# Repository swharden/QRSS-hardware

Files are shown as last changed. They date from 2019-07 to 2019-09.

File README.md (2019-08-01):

# QRSS Hardware

This repository is an evolving collection of notes and resources related to QRSS hardware (TX and RX) that I (Scott Harden, AJ4VD) find useful. Eventually this work will become a webpage, but for now it's a GitHub repository which makes it easy to edit.

* **[Recently spotted AJ4VD QRSS signals](/spots)**
* Hardware notes are in the [builds](/builds) folder 
* New to QRSS?
  * [What is QRSS?](https://www.qsl.net/m0ayf/What-is-QRSS.html)
  * Join the [_QRSS Knights_ mailing list](https://groups.io/g/qrssknights)
  * See live signals around the world with [QRSS Plus](http://www.swharden.com/qrss/plus/)

### Modular QRSS Transmitter for Experimentation

The transmitter I built uses separate modules. I designed my transmitter this way so I can get a signal on the air, then work toward improving individual modules individually. My current design supports FSK (frequency-shift keying), OOK (on-off keying), and adjustable power output, and synchronization with GPS time. 

Modules are all individually powered and use SMA connectors for inputs/outputs. By applying this [SOLID](https://www.youtube.com/watch?v=TMuno5RZNeE&t=15m50s) principle to hardware development, the system easy to refactor (because it reduces _coupling_) and individual units are easy to test (because they have a defined _interface_).

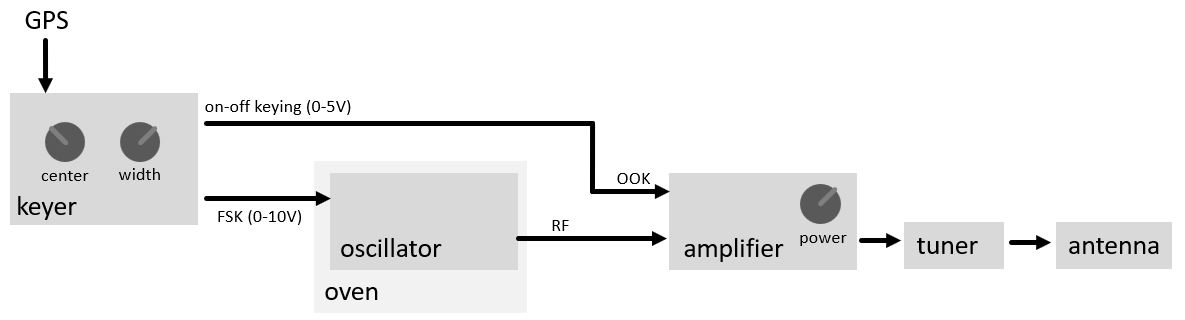
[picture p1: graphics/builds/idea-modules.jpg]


* **oscillator** - Colpitts, 10.140 MHz crystal, no inductors (so SMT PCB is easy), outputs about 1 mW
* **oscillator oven** - uses two power 50 Ohm resistors to heat the _entire oscillator enclosure_ to above ambient room temperature. Thermistor is used for temperature sensation. By heating an entire metal-enclosed oscillator module, the entire oscillator circuitry (not just the crystal) becomes thermo-stable.
* **keyer** - based on an ATTiny2313 microcontroller. Keying is pulse-width modulated (PWM), and OOK output is also provided. Keyer has voltage combiner which has separate knobs to adjust center frequency and FSK width. Output is a single voltage for the oscillator, and a signal voltage for the amplifier. While it's currently configured for OOK, an analog voltage could be sent to the amplifier to control power output from software.
* **GPS** - To start messages at precise 10 minute intervals a GPS module (Neo-6M) is used. Rather than tap into the 1PPS signal line, I'm using the microcontroller to parse the serial data coming off the chip and begin transmitting at precise times.
* **amplifier** - currently an IRF510 final transistor with  74HC541 buffer pre-amplifier. The 74HC541's enable lines are controlled by the keyer to provide OOK. A potentiometer sets the power output. The current design has been tested to over 10W but this is an unnecessary (and undesirable) power level for QRSS.
* **frequency counter** - this is an independent project at the moment. I'm creating a USB frequency counter which will be useful for graphing frequency stability over time (and its relationship with temperature). I'll link to this once I have it tested/working.
* **antenna** - 30m dipole in my attic (Gainesville, Florida, USA)

### Photographs

This is a work in progress so the enclosures (if they even exist) are pretty crude. Additional photographs (and schematics) at various stages of the design process can be found in sub-folders of this repository. As individual modules are improved, these photographs will be updated.

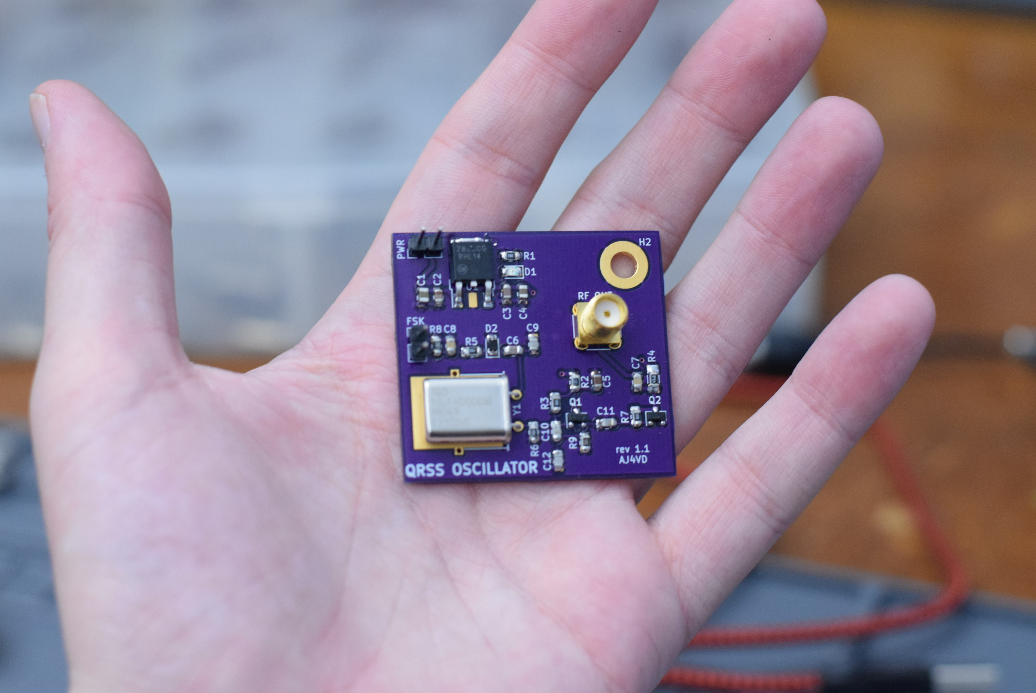
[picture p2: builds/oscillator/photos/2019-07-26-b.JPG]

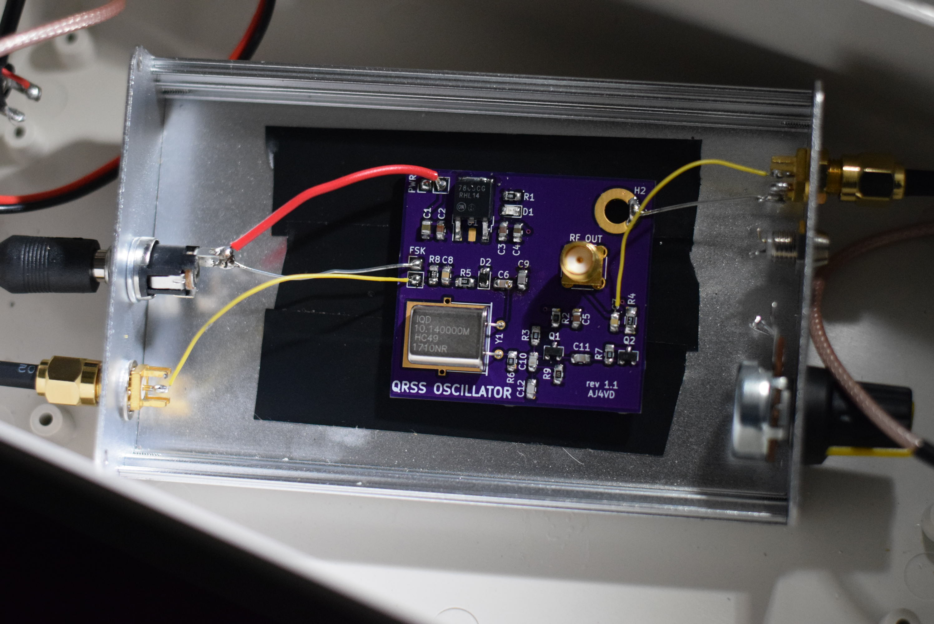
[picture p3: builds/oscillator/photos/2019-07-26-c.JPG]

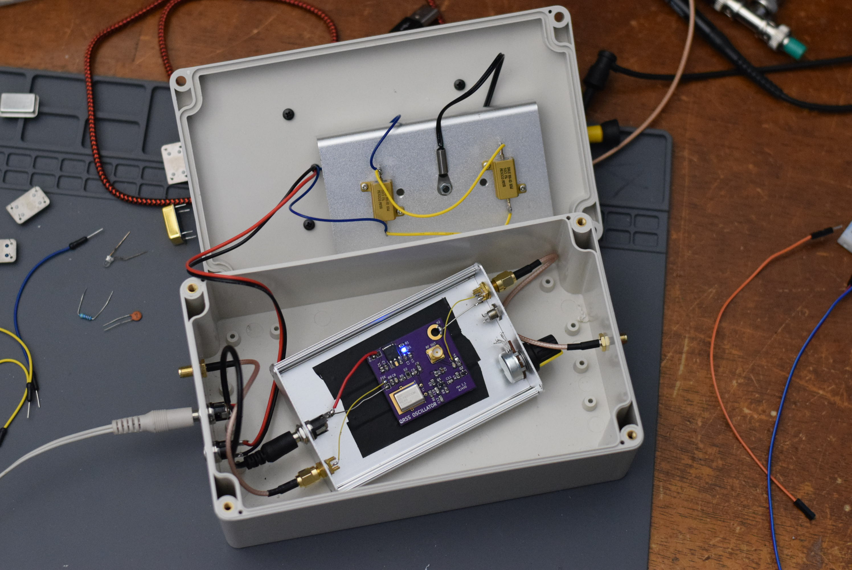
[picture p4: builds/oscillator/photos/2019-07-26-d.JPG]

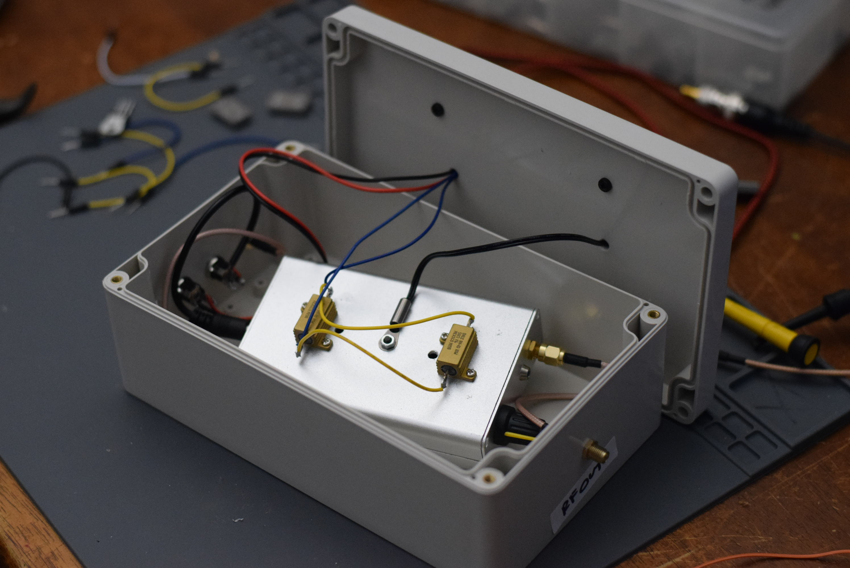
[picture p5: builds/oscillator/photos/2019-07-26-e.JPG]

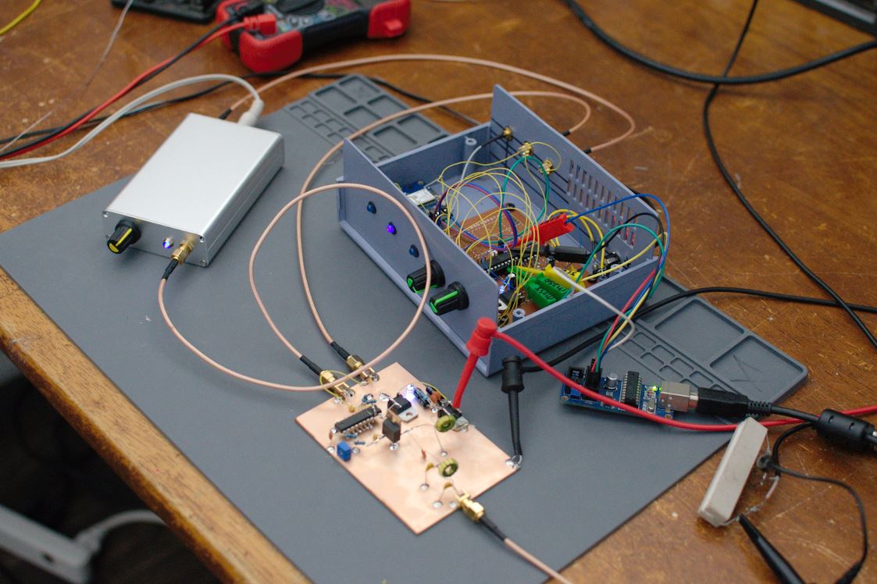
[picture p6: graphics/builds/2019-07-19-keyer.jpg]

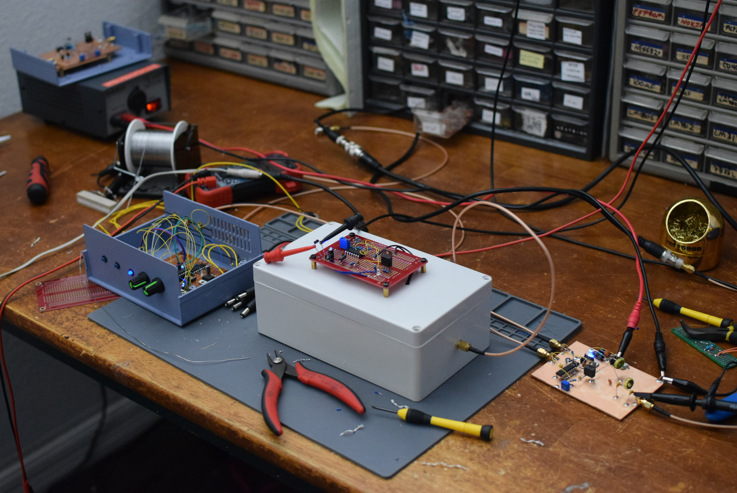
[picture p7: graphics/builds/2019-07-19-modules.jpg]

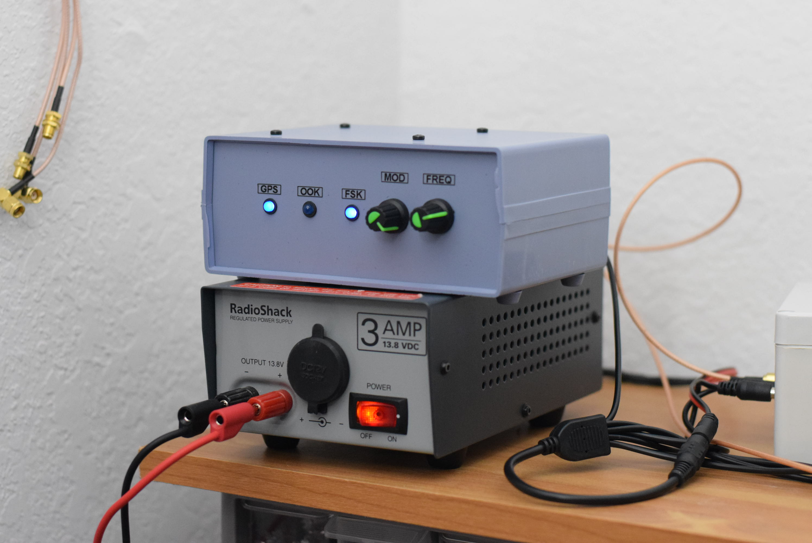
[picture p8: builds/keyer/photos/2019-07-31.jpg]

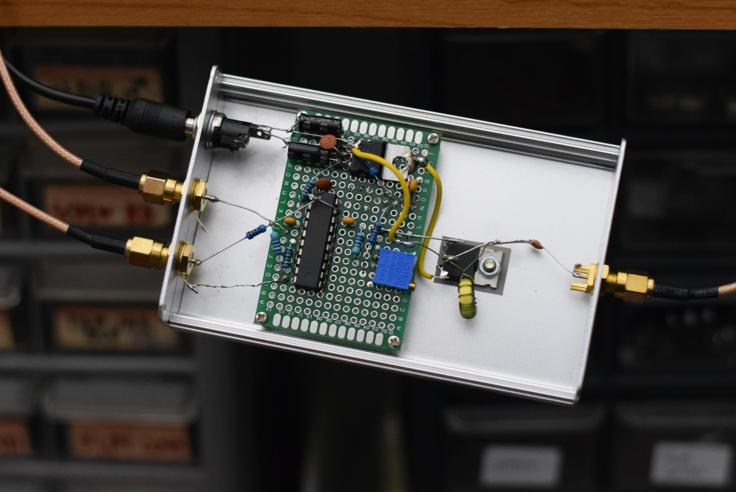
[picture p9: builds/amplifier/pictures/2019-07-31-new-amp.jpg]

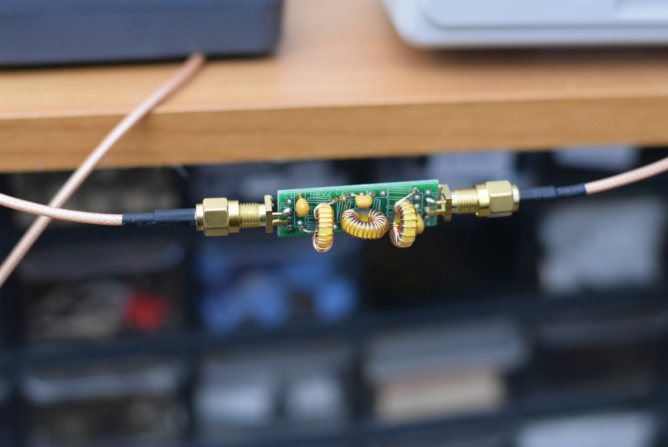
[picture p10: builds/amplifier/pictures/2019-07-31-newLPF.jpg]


### Project goals

I experimented with QRSS on and off over the last decade, but all of my designs were pretty crude. Now that I have more experience, knowledge, and resources, I'd like to get back into the hobby.

There are a lot of crystal oven designs and chassis heater designs out there, and I'd like to get better at testing different designs. This requires precision temperature and frequency measurements and involves using a PC for data-logging and analysis. I'd like to get a better understanding of the temperature vs. frequency profile not just of crystals, but of the entire oscillator circuit. I'm interested in developing a SMT oscillator board with the temperature controller built-in (using SMT resistors to heat the PCB, temperature-stabilizing the entire oscillator rather than just the crystal).

I'd also like to improve QRSS Plus, and see about creating an open-source QRSS spectrograph like Argo now that I have experience developing Windows applications with C#. While my previous efforts (in Python) were interesting, I now have a strong appreciation for click-to-run software that works with minimal complexity.

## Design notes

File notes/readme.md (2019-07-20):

# QRSS Notes

## Notable QRSS TX Design Pages
* **Dave Hassall (WA5DJJ)** built multiple transmitters and has [great web pages](http://www.zianet.com/dhassall/QRSS_A.html) that describe their design. The first two builds are fully analog:
  * [MEPT v1](http://www.zianet.com/dhassall/QRSSMEPT1.html) uses 2n2222 for oscillator, buffer, and final. The oscillator board is insulated. Initially it output 50 mW, but was later modified to output up to 900 mW.
  * [MEPT v2](http://www.zianet.com/dhassall/QRSSMEPT2.html) uses a resistor crystal oven. The final amplifier are 3x 2n2222 transistors in parallel for 250mW output.
* **VK1TKA** made a solar-powered MEPT and [documented the build](http://clayton.isnotcrazy.com/mept_v1)
  * The microcontroller is clocked at the transmitter frequency and CKOUT is amplified with a [74HC245](https://assets.nexperia.com/documents/data-sheet/74HC_HCT245.pdf) (500 mW max dissipation) in push-pull configuration as the output driver
  * It uses an interesting temperature compensation scheme (in software) 

## Hardware
* [Genesis Q5 transmitter](http://www.genesisradio.com.au/Q5/) uses a 74HC04N as an oscillator and also to buffer and amplify the output.
* [Using 74HC240 as a buffer amplifier](http://py2ohh.w2c.com.br/trx/digital/rfdigital.htm)

## Software
* [Argo](https://digilander.libero.it/i2phd/argo/) - a spectrograph for QRSS
* [QrssPig](https://github.com/MartinHerren/QrssPiG) - a QRSS grabber for Raspberry Pi (in Python)
* [Spectran](http://www.sdradio.eu/weaksignals/spectran.html)
* [SpectrumLab](https://www.qsl.net/dl4yhf/spectra1.html)

## Oscillator Designs
[Crystal Oscillator Circuits by VK5SRP](/graphics/diagrams/crystal-oscillator-notes-VK5SRP.pdf)


## Designs at a glance

### Transmitters (and oscillators)
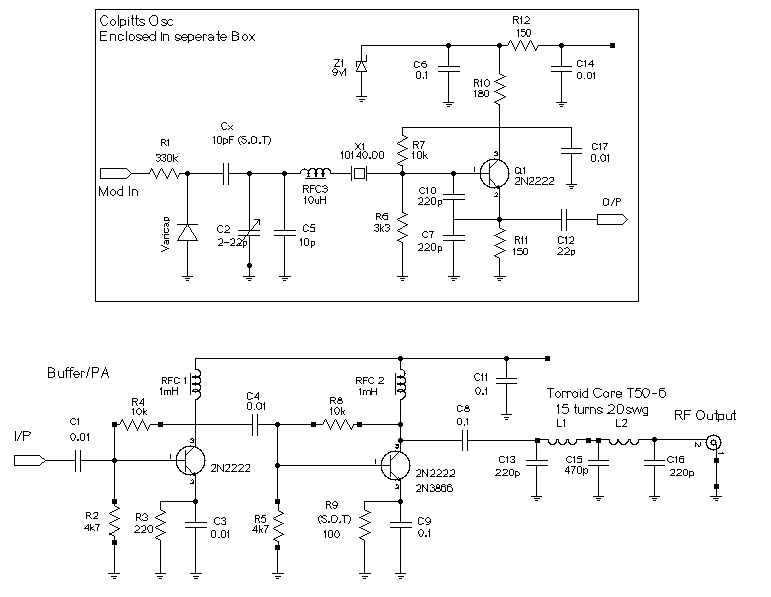
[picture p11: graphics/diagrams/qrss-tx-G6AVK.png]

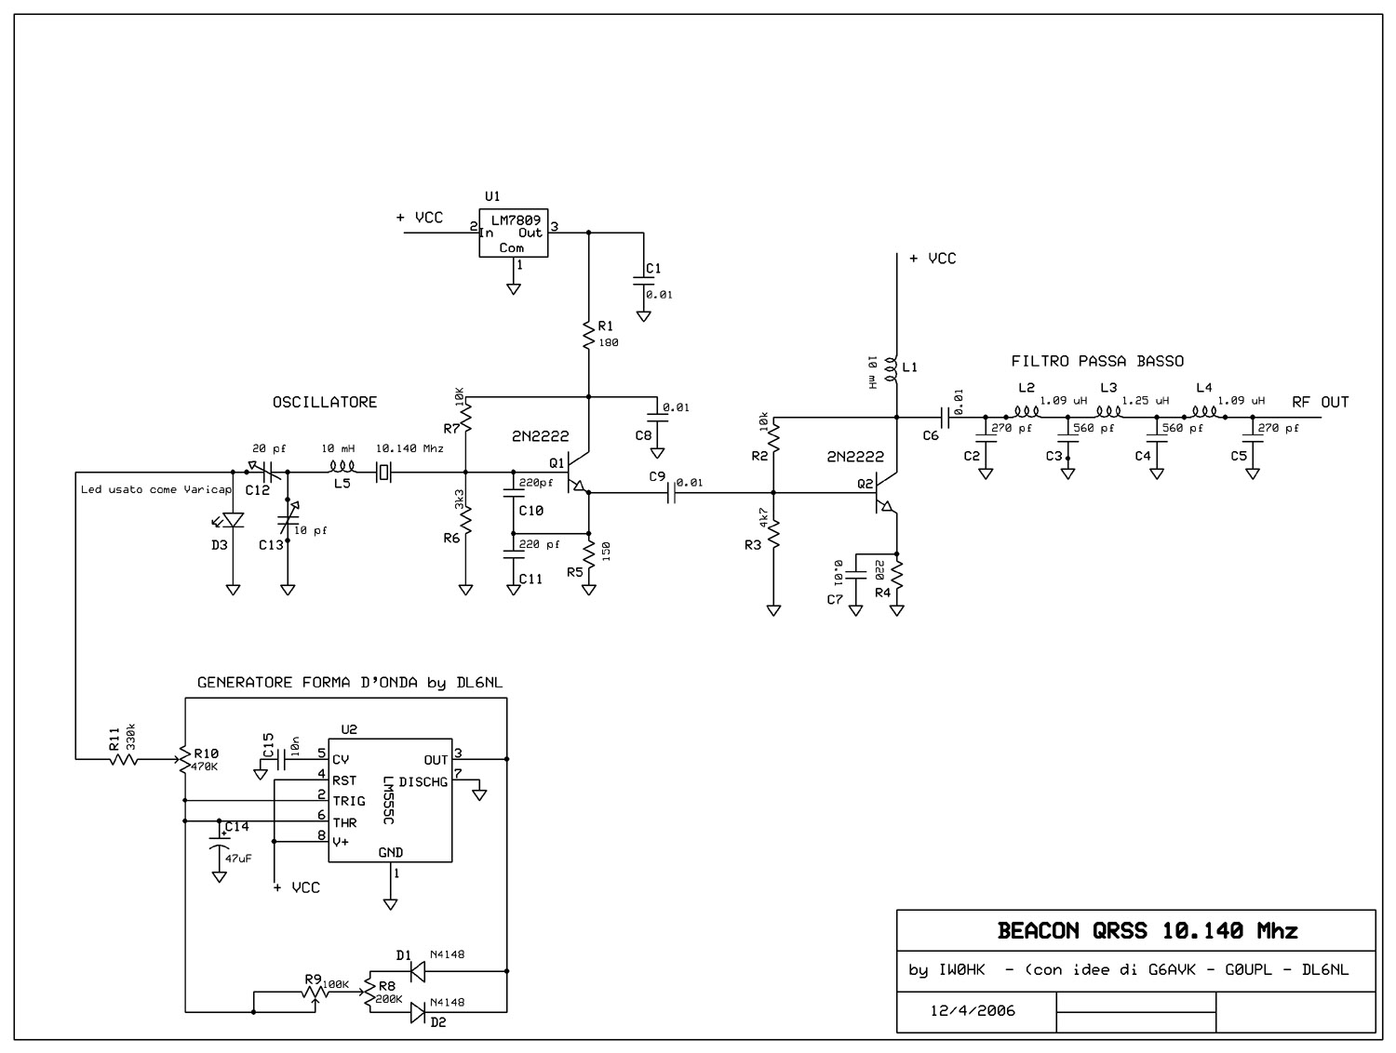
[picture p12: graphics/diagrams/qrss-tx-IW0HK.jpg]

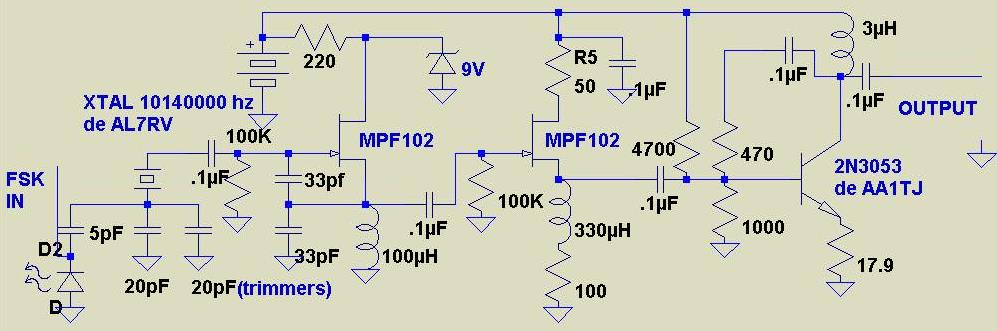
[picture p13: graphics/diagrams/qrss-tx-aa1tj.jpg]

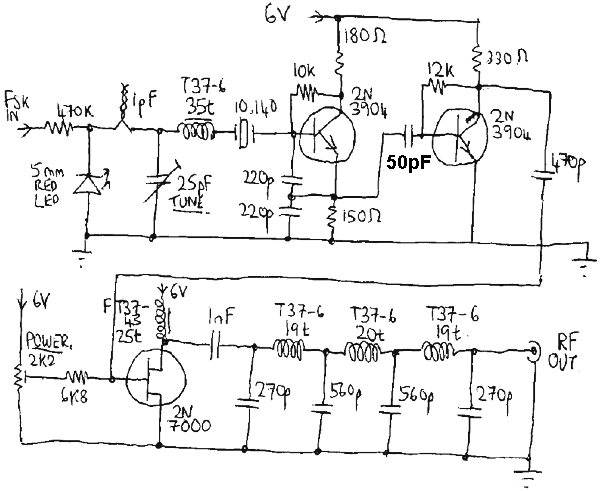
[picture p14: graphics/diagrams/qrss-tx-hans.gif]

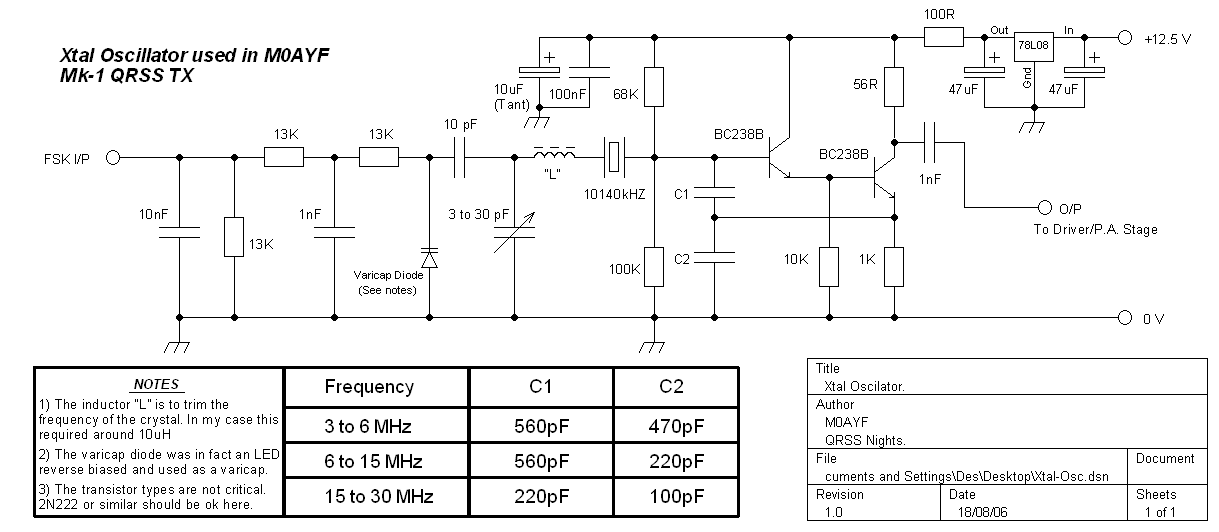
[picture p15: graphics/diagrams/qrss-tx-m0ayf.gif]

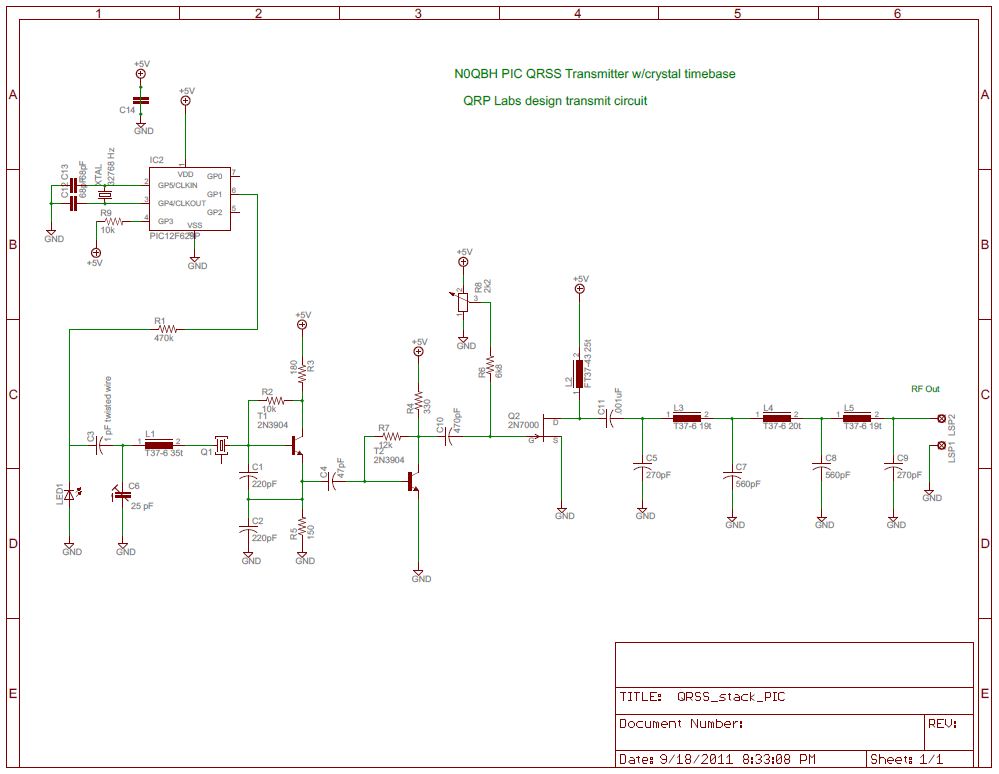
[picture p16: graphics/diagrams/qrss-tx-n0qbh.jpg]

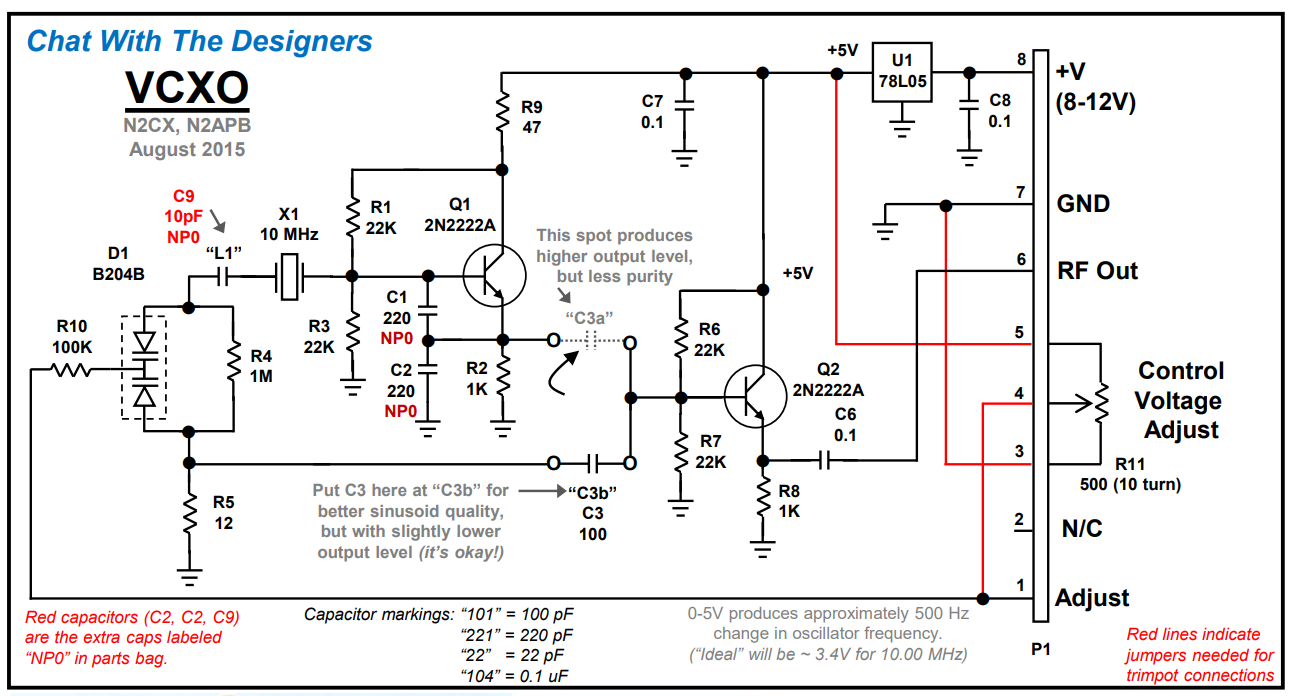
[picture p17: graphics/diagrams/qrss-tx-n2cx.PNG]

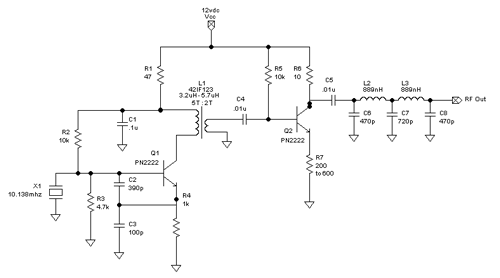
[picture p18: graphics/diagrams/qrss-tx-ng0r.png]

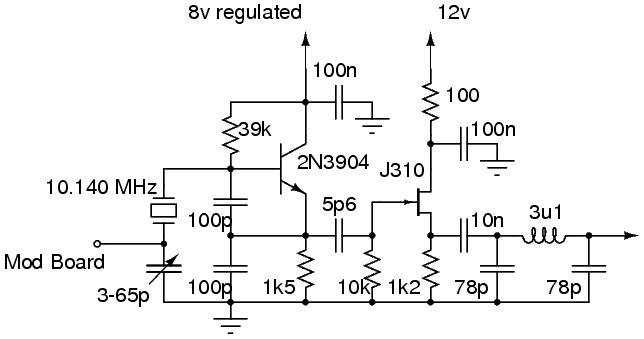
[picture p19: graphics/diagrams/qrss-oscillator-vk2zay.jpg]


### Receivers
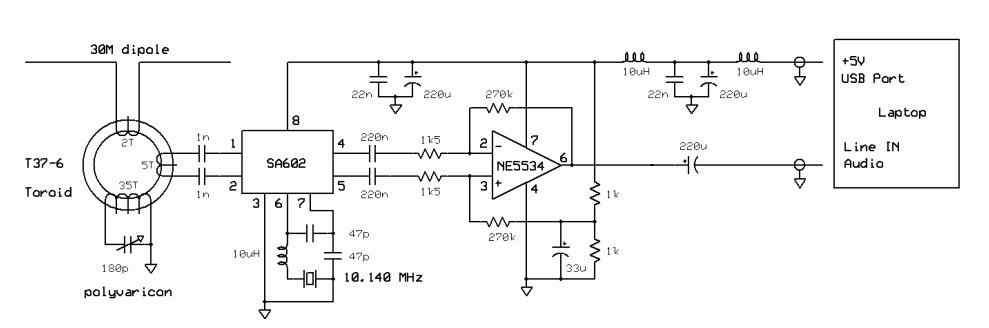
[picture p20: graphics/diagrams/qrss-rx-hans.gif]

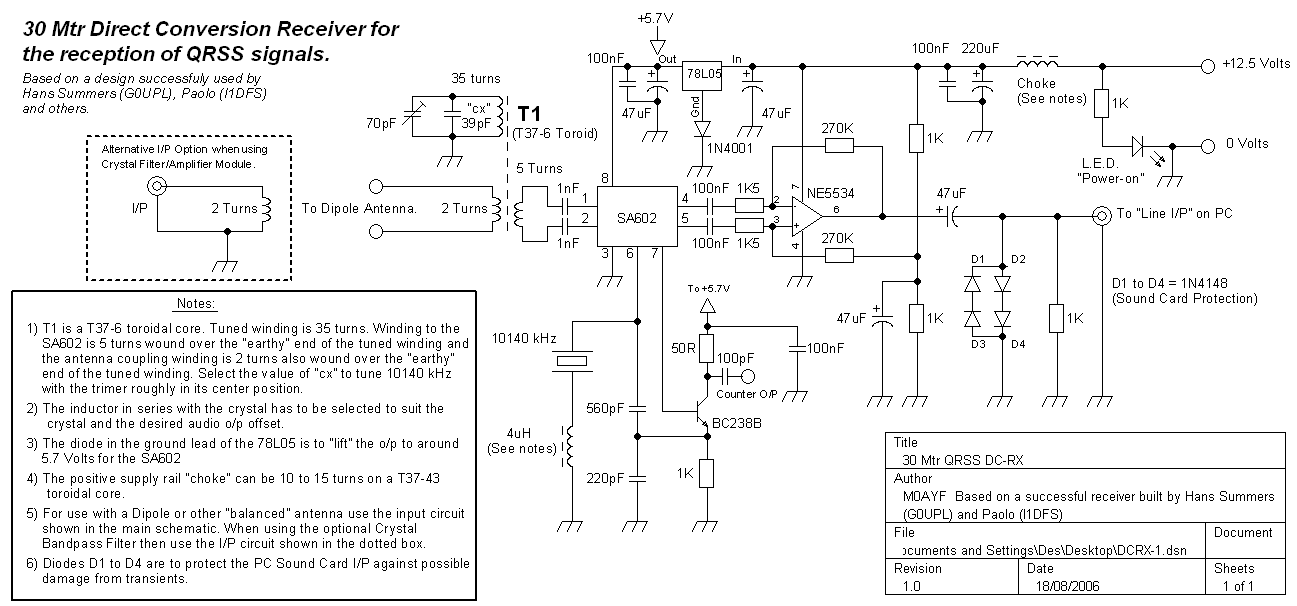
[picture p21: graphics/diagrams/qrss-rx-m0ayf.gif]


## FSK
These are notes related to shifting a crystal oscillator's frequency.

### [High Frequency VCO Design and Schematics](https://www.qsl.net/va3iul/High_Frequency_VCO_Design_and_Schematics/High_Frequency_VCO_Design_and_Schematics.htm)

### [Variable Frequency Oscillators](http://ftp.unpad.ac.id/orari/orari-diklat/teknik/homebrew/pcb/crystal-sets-to-sideband/chap10.pdf)

This text has _50 secrets of avoiding drift_ and _varactor tuning_ sections which are worth reviewing.

There's also a good section about building precision power supplies for VFOs.

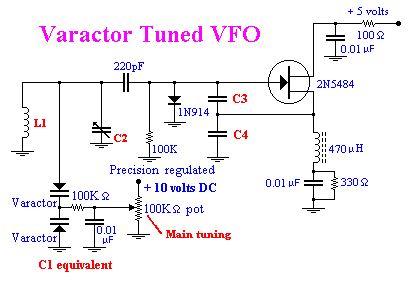
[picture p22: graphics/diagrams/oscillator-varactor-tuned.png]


Use a varactor as a temperature-compensated VFO

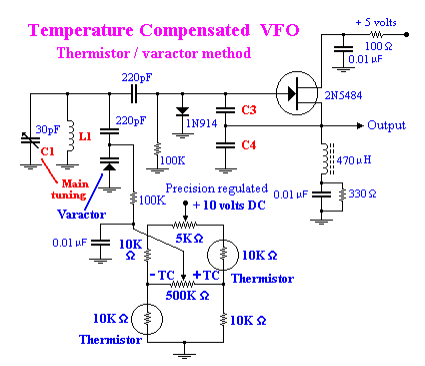
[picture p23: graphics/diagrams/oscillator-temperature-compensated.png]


### vk2zay Fine and Coarse Tuning
http://www.vk2zay.net/article/181

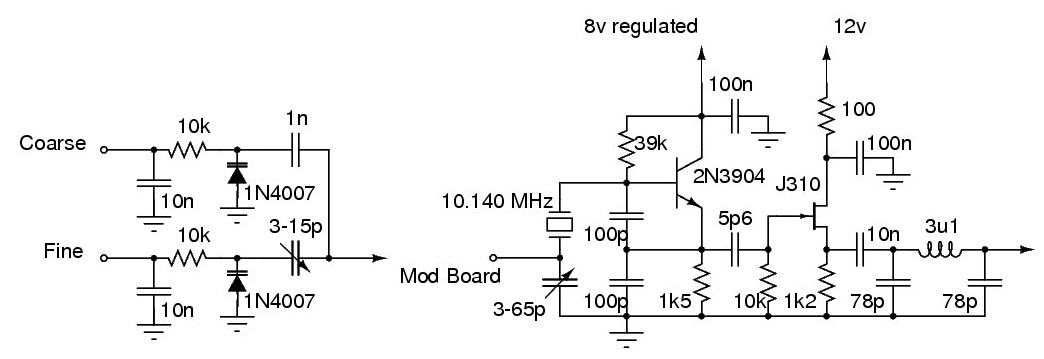
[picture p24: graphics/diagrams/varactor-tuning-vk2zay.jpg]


I tried building designs like this but it's too frustrating. Every time you adjust the coarse, the FSK distance changes. Further, it changes nonlinearly (with bigger swings when the voltage is near zero). Maybe I used a sub-ideal varactor in my tests (a reverse-biased LED).

# QRSS Oven Designs

## Links

* [Temperature Control Circuits](http://www.techlib.com/electronics/ovenckts.htm)
* [Crystal Oven Controller](https://www.w6pql.com/crystal_oven_controller.htm) (W6PQL)
* [Crystal Ovens for QRSS Applications](https://www.qsl.net/m0ayf/Crystal-Ovens.html) (M0AYF)
* [A simple crystal oven/heater that uses no power resistors](http://ka7oei.blogspot.com/2018/01/a-simple-crystal-ovenheater-that-uses.html) (KA7OEI)
* Temperature Controllers for QRSS [Part 1](http://pensacolasnapper.blogspot.com/2011/03/temperature-controllers-for-qrss.html),  [Part 2](http://pensacolasnapper.blogspot.com/2011/03/temperature-controllers-for-qrss-part-2.html), and [Part 3](http://pensacolasnapper.blogspot.com/2011/03/temperature-controllers-for-qrss-part-3.html) (W4HBK)
* [Use a transistor as a heater](https://www.edn.com/design/components-and-packaging/4371386/Use-a-transistor-as-a-heater)

## Temperature Sensors
* [NTC thermistor](https://www.mouser.com/ProductDetail/Vishay-BC-Components/NTCS0805E3103JMT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) 0805 ($0.53) 10K ambient
* [LM335](https://www.mouser.com/ProductDetail/STMicroelectronics/LM335Z?qs=sGAEpiMZZMuaKyt%2FjIB%2FpgcqLP%252BGkGYM) ($0.48) output voltage (zener breakdown) varies directly (and linearly) with temperature (10mV/K).
* [LM84](https://www.mouser.com/ProductDetail/Texas-Instruments/LMT84LP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) ($0.83) output voltage varies inversely to temperature. 50C is 750 mV.

## Heater Elements
* [chassis mount wirewound power resistors](https://www.mouser.com/Passive-Components/Resistors/Wirewound-Resistors/Wirewound-Resistors-Chassis-Mount/_/N-7fx9g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|0) ($1-2)

## Typical Op-Amp Designs
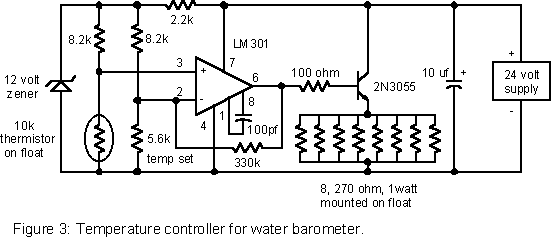
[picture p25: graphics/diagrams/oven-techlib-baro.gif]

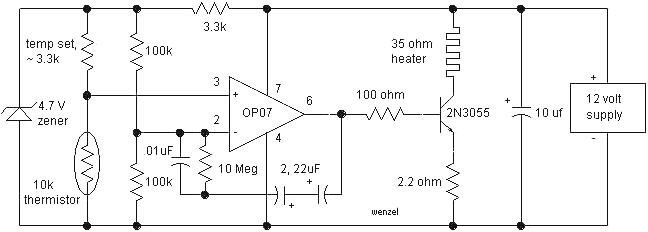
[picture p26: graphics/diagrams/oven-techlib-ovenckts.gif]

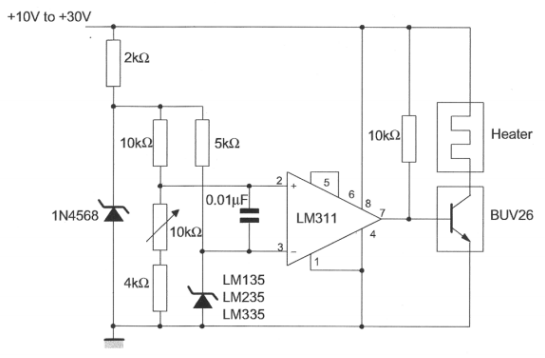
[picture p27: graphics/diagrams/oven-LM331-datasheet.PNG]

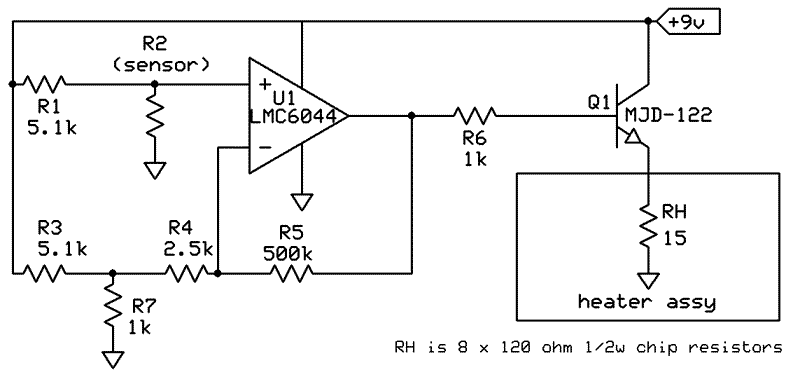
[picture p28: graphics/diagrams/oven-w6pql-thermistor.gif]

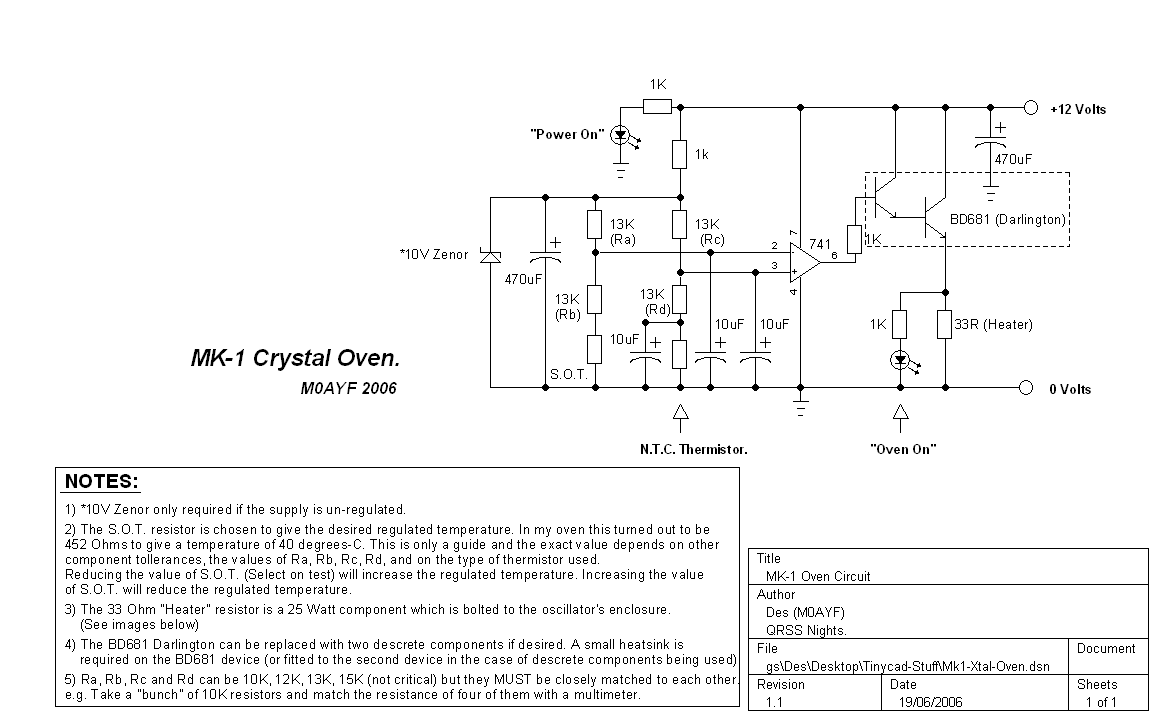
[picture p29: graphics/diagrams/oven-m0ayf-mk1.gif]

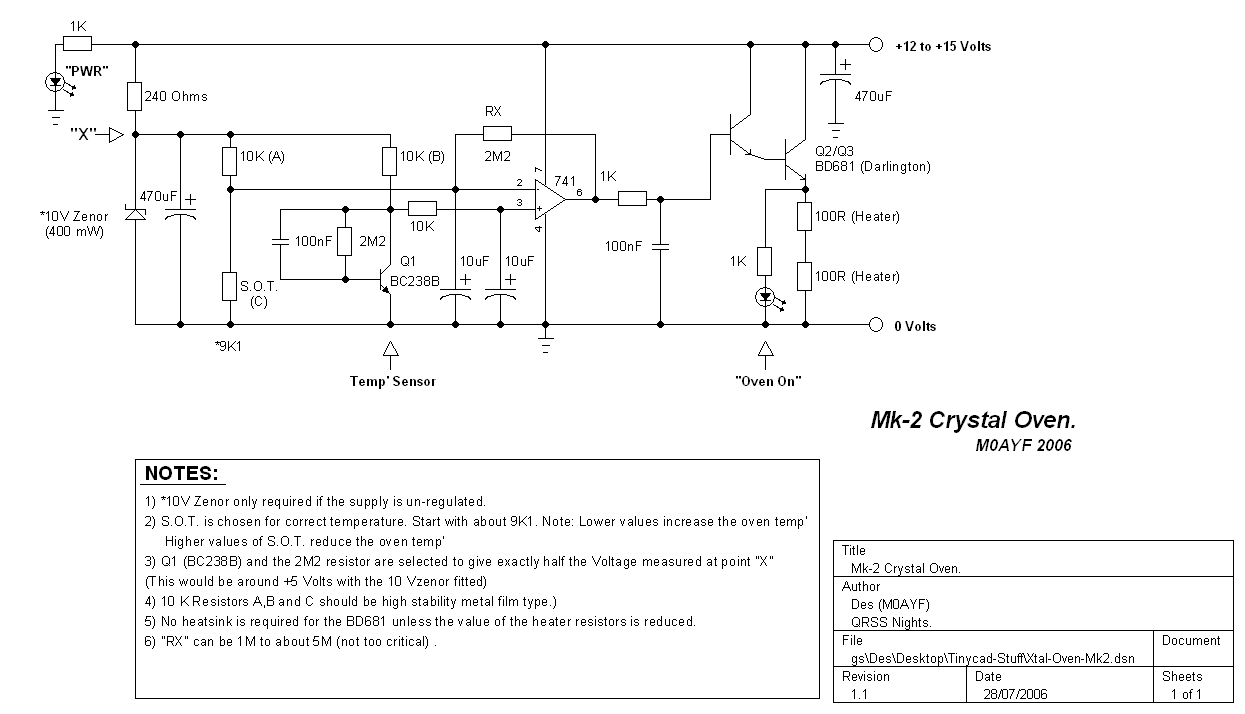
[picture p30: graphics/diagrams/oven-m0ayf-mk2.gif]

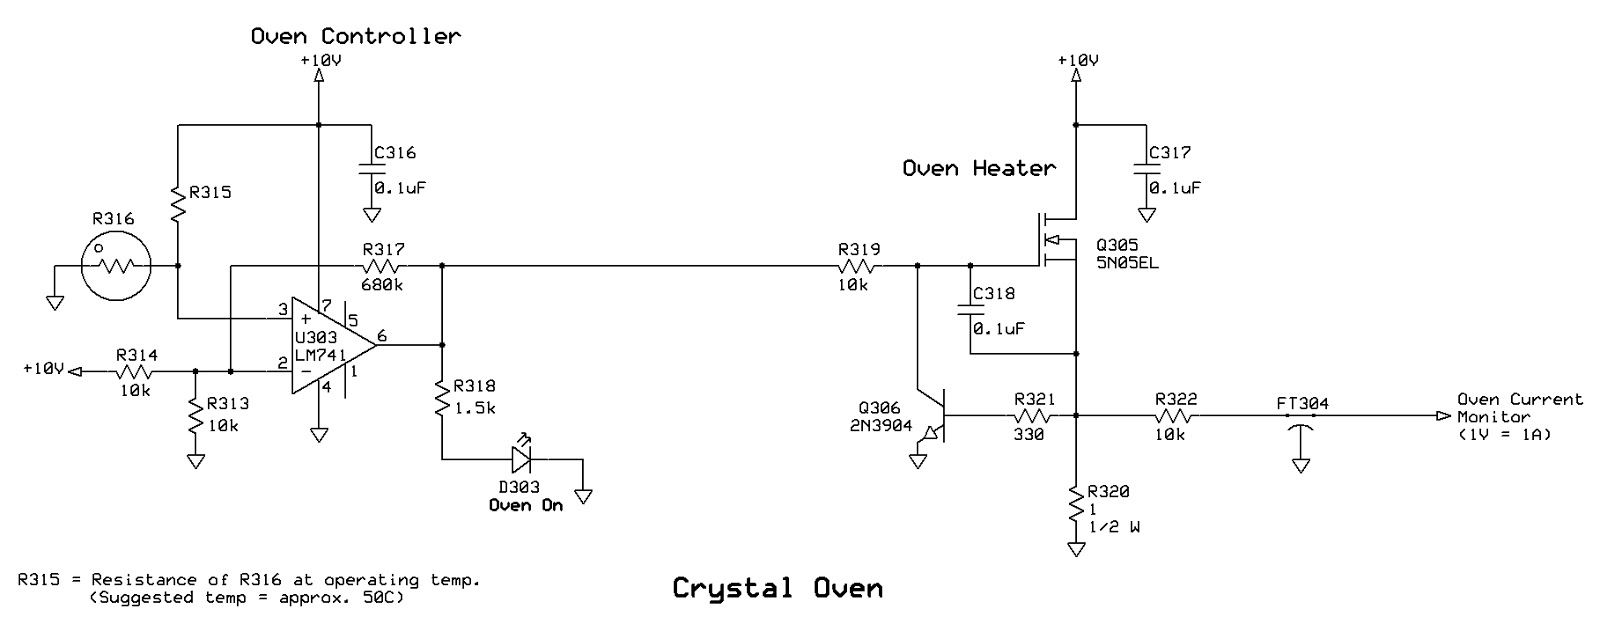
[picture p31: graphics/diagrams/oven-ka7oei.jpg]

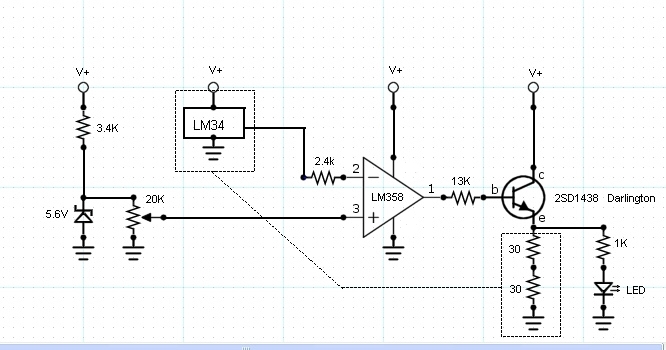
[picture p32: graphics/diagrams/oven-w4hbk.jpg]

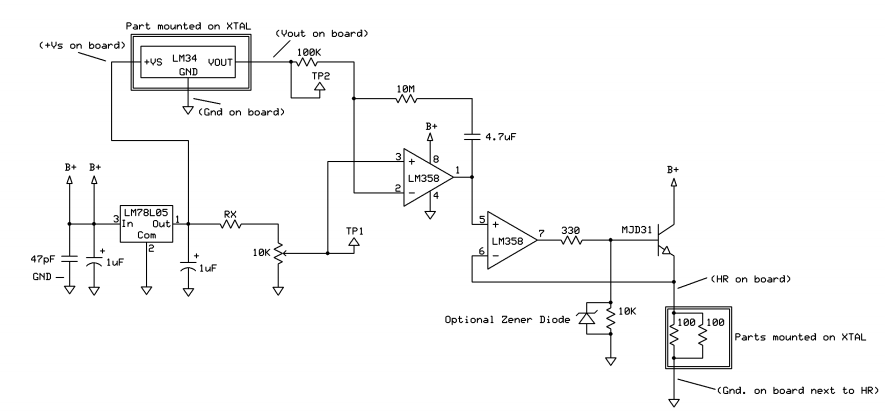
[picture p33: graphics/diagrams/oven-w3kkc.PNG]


## Alternate Designs
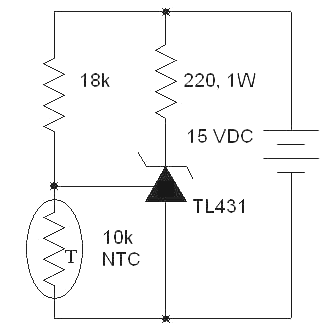
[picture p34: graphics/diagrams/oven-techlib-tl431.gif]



# Notable Components

This is a list of components I frequently design with. By keeping links to their Mouser pages all in one place it makes ordering easy. It also makes retrieving datasheets simple and fast.

* special passives
  * [10uF capacitor (35V)](https://www.mouser.com/ProductDetail/Taiyo-Yuden/GMK212BBJ106KG-T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) 0805 ($0.61)
  * [10uF capacitor (10V)](https://www.mouser.com/ProductDetail/Taiyo-Yuden/LMK212ABJ106MG-T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) 0805 ($0.15)
  * [47 Ohm resistor (500 mW)](https://www.mouser.com/ProductDetail/Panasonic/ERJ-P06F47R0V?qs=sGAEpiMZZMtlubZbdhIBIK7FbVYKWV6WeeFY5DwaNCk%3D) 1206 ($0.17)
* [10.140 MHz crystal](https://www.mouser.com/ProductDetail/IQD/LFXTAL013480Bulk?qs=e4%2FAndAAwgLefIQQ1kDEyw%3D%3D) ($0.75)
* [ATTiny2313](https://www.mouser.com/ProductDetail/Microchip-Technology-Atmel/ATTINY2313A-SU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) SOIC-20 ($1.12)
* [74HC04](https://www.mouser.com/ProductDetail/Toshiba/74HC04DBJ?qs=sGAEpiMZZMutVWjHE%2FYQw9wp2KmMZae1rDJE3jT16hQ%3D) SOIC-14 ($0.40)
  * 6 inverting gates
  * 6V max operating voltage
  * 25mA max output current (6x = 150mA)
  * 500mW max total power output
* [74HC240](https://www.mouser.com/ProductDetail/ON-Semiconductor/MC74HC240ADWR2G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) (8 gates) SOIC-20 ($0.58)
  * 8 inverting gates
  * 6V max operating voltage
  * 35mA max output current (8x = 280mA)
  * 450mW max total power output
* [74HC541](https://www.mouser.com/ProductDetail/Texas-Instruments/SN74HC541PWR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) (8 gates, all on the same side!) TSSOP-20 ($0.58)
  * 6V max operating voltage
  * 20mA max output current (8x = 120mA)
  * recommended 6mA output max (8x = 48mA)
* [7805 regulator (1A)](https://www.mouser.com/ProductDetail/ON-Semiconductor/MC7805CDTRKG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) DPAK-3 ($0.56)
* [SMA connector](https://www.mouser.com/ProductDetail/LPRS/SMA-CONNECTOR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) ($1.08)
* varactor - use an 0805 LED for now
* [ferrite bead](https://www.mouser.com/ProductDetail/Taiyo-Yuden/BK2125LM252-T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) (200 mA, ~2kOhm at 10MHz) 0805 ($0.12)

## Online Calculators
* [capacitor impedance calculator](http://www.learningaboutelectronics.com/Articles/Capacitor-impedance-calculator.php)
* [inductor impedance calculator](http://www.learningaboutelectronics.com/Articles/Inductor-impedance-calculator.php)

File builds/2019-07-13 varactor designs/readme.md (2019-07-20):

# Varactor FSK Designs for QRSS

For QRSS it's convenient to have 2 frequency shift adjustments: a coarse one to set frequency (~200 Hz), and a fine one for FSK (5 Hz). 

Most QRSS TX designs use a variable capacitor to set the coarse adjustment, but I don't like that design because it means you have to open your enclosure every time you want to shift frequency:



VK2ZAY shows a design that pulls one leg of a crystal using two varactors, the magnitude of each is controlled by a series capacitor:



I tried building designs like this I find them very frustrating. 

Issue 1: coarse adjustment modifies FSK shift.
Every time I adjust the coarse voltage, the FSK distance changes. Consider a coarse adjustment resulting in a small capacitance: the fine FSK can produce a large shift. When the coarse produces a large capacitance, the fine FSK has little effect. If your fine FSK is a perfect 5Hz and you adjust the coarse frequency, your FSK is no longer 5Hz.

Issue 2: ~varactor diodes are too variable at low voltages. For stable operation it helps to run a varactor at several volts. I fix this by running the FSK voltage through a voltage divider _to VCC_ (not ground), and use the high-pulled fractional voltage on the varactor.~ Actually this was only a problem for reverse-biased LEDs. Real varactor diodes worked fine at low voltages.



***NOTE TO SELF: Use a real varicap diode! You have [BB132](https://uk.rs-online.com/webdocs/0466/0900766b80466490.pdf) (around 60 pF) and [BB149A](http://pdf.datasheetcatalog.com/datasheet/NXP_Semiconductors/BB149A.pdf) (around 20 pF) so you can get tons of swing by using one! Stop using reverse-biased LEDs!*** A reverse-biasd blue LED measured 60 Hz swing (with a lot of additional fixed capacitance in place to get near center frequency). Replacing this with a BB132 (I had to remove a 5pA cap to compensate) I got a swing of 159 Hz. That's more than double, and that's just one varicap. You can stack them in parallel. **Real varicaps dont mind low voltage*** I found out, so don't worry about avoiding that super low region like with the LED.

This is a design I came up with that seems to be treating me well so far. Fixed capacitors (optionally populated) set the frequency so the crystal oscillates in the QRSS band. The coarse adjustment moves the signal around the QRSS band (100Hz). The fine adjustment is pulled high (ideal for varactor stability and linearity) through a divider, making it fine. Adjust R4 to control how wide the FSK can be.

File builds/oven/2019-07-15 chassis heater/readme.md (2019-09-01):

# Chassis Heater / Crystal Oven

This folder documents my thoughts and experiments related to development of a chassis heater. Since I'll build the chassis heater inside an insulated container, I'll refer to it as a chassis oven.

### Design

After running the numbers for a bunch of different power/resistor combinations, I decided to work with 50-Ohm power resistors. I'd love to have more 50-Ohm power resistors on hand to use for making dummy loads.

I settled on this part: [50 Ohm (+/- 1%) 12.5 watt resistor](https://www.mouser.com/ProductDetail/Vishay-Dale/RH01050R00FE02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) ($2.64)

Running 12V through a single resistor would burn 2.88W of power as heat. If we wanted more heat we could add additional resistors in parallel, but this should be okay.

### Circuit
After the above considerations, this is what I came up with. I made it on a breadboard and it works well.



* You can add multiple R4s in parallel for faster heating
* I ended-up replacing the TIP122 (Darlington transistor) with an IRF510 (N-channel MOSEFET) for better linear operation (since the TIP122 has such high gain)
  * This works great and the IRF510 rests partially on once stabalized
  * The IRF510 gets hot! Maybe you can mount that to the chassis too?
* You can supply it with dirty power and it doesn't seem to affect oscillator performance
* I use a multi-turn potentiometer for RV1
* R6 sets hysteresis
  * Large values promote squishy temperature control. 
  * Small values will faster responses but may oscillate
  * Remove R6 for bang-bang operation
* I suspect this design could be used as a _crystal_ oven
  * Replace Q1 with a 2N2222
  * Replace R4 with a 680 Ohm 1/4-watt resistor (~17 mA, ~200 mW)
  
  ### Photos
  
  
  
  ### More Notes
  I experimented more on 2019-08-31:
  
  * Switched to an LM335 (not a thermistor) super-glued to the chassis
  * I target 3.10 mV (310 Kelvin = 37C or 100F)
  * Can use LM7805 for op-amp and divider since we are using low voltages
  * A tip122 is cheaper than the IRF510 and works fine

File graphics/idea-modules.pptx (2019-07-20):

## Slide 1

GPS

width

on-off keying (0-5V)

center

keyer

FSK (0-10V)

oscillator

OOK

amplifier

power

oven

RF

tuner

antenna

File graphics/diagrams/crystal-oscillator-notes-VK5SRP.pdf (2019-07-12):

Crystal Oscillator Circuits – Page 1

Radio receivers and transmitters both require a precise frequency reference, and this reference was until recently almost always provided by a crystal oscillator. A crystal oscillator is an electronic circuit that uses the mechanical resonance of a vibrating crystal to generate a sinusoidal electronic signal at a very precise frequency. The translation by certain materials of a mechanical impulse to an electrical oscillation is called the piezoelectric effect. The most common type of piezoelectric resonator until recently was the quartz crystal and electronic circuits designed around them are called crystal oscillators.

Piezoelectricity was discovered by Jacques and Pierre Curie in 1880. The first crystal-controlled oscillator was constructed at Bell Laboratories in 1917 by Alexander Nicholson using a crystal of Rochelle salt. Walter Cady, a professor at Wesleyan University, built the first quartz crystal oscillator in 1921. By 1926, quartz crystals were used to control the frequency of AM radio broadcast transmitters and were widely used by amateur radio operators.

In crystal oscillators, the usual electrical resonant circuit is replaced by a mechanically vibrating crystal. The crystal (usually quartz) has a high degree of stability in holding constant at whatever frequency the crystal is originally cut to operate. The crystal oscillators are, therefore, used whenever great stability is needed, for example, in communication transmitters, and receivers, digital clocks etc.

The Piezo-electric effect is when a mechanical pressure is applied across the faces of the crystal, a voltage proportional to the applied mechanical pressure appears across the crystal. Conversely, when a voltage is applied across the crystal surfaces, the crystal is distorted by an amount proportional to the applied voltage. An alternating voltage applied to a crystal causes it to vibrate at its natural frequency.

Besides quartz, the other substances that exhibit the Piezo-electric effect are Rochelle salt and Tourmaline. Rochelle salt exhibits the greatest piezoelectric effect, but its applications are limited to manufacture of microphones, headsets and loudspeakers. It is because the Rochelle salt is mechanically the weakest and strongly affected by moisture and heat.

Tourmaline is most rugged but shows the least Piezo-electric effect. Quartz is a compromise between the piezoelectric effect of Rochelle salt and the mechanical strength of tourmaline. It is inexpensive and readily available in nature. It is mainly the quartz crystal that is used in radio frequency oscillators.

Equivalent circuit of a quartz crystal resonator

To analyse the electrical response of a quartz crystal resonator, it is very often useful to depict it as the equivalent electrical components that would be needed to replace it. This equivalent circuit is can then be used to analyse its response and predict its performance as in the diagram below:

Crystal Oscillator Circuits – Page 2

The equivalent circuit given below is often called the 4-parameter crystal model and it is sufficient for many calculations and to illustrate the operation of the crystal.


Fig b - Quartz crystal theoretical equivalent circuit

It is possible to equate these theoretical constituent components to real physical attributes of the crystal:

- L: The inductance arises from the mass of the material.
- C1: This capacitance arises from the compliance of the crystal.
- R: This element arises from the losses in the system. The largest of these arises from the frictional losses of the mechanical vibration of the crystal.
- Co : This capacitance in the theoretical quartz crystal equivalent circuit arises from the capacitance between the electrodes of the crystal element. This is often referred to as the shunt capacitance.

Apart from their use in oscillators, quartz crystals find uses in filters. Here they offer levels of performance that cannot be achieved by other forms of filter. Often several crystals may be used in one filter to provide the correct shape. The picture below show a home made band pass crystal ladder filter.


For use in electronic oscillators, the crystal is suitably cut and then mounted between two metal plates, as shown in this old FT-243 example. You can just make out the actual Quartz between the two metal plates. The copper plates in the Bakelite housing connect to the connection pins, then there is a sandwich of a metal plate, the actual crystal, another metal plate, a spring and lastly the insulating plate that keeps the assembly from touching the metal cover.

Crystal Oscillator Circuits – Page 3


Although the crystal has electro-mechanical resonance it’s resonant action can be represented by an electrical resonance circuit, as shown in fig. (b). The crystal actually behaves as a series R-L-C circuit in parallel with CM where CM is the capacitance of the mounting electrodes (stray capacitance). Because the crystal losses, represented by R, are small the equivalent crystal Q is high-typically 20,000. Values of Q up to 106 can be obtained from crystals in actual circuit. Because of presence of CM, the crystal has two resonant frequencies. One of these is the series resonant frequency and the crystal impedance is very low. The other is parallel resonance frequency Fp which is due to parallel resonance of capacitance CM and the reactance of the series circuit. In this case crystal impedance is very high. The impedance versus frequency curve of the crystal is shown in the figure below. In order to use the crystal properly it must be connected in a circuit so that its low impedance in the series-resonant operating mode or high impedance in the anti-resonant or parallel resonant operating mode is selected.

The two frequencies are very close to each other. It is due to the fact that the ratio C/CM is very small. To stabilize the frequency of an oscillator, a crystal may be operated at either its series or parallel resonant frequency.

Crystal Oscillator Circuits – Page 4


Colpitts Quartz Crystal Oscillator

Crystal oscillator circuits are generally constructed using bipolar transistors or FETs. This is because although operational amplifiers can be used in many different low frequency (≤100kHz) oscillator circuits, operational amplifiers just do not have the bandwidth to operate successfully at the higher frequencies suited to crystals above 1MHz.

The design of a Crystal Oscillator is very similar to the design of the L and C Colpitts Oscillator except that the LC tank circuit that provides the feedback oscillations has been replaced by a quartz crystal as shown below.

Colpitts Crystal Oscillator


This type of Crystal Oscillators are designed around a common collector (emitter-follower) amplifier. The R1 and R2 resistor network sets the DC bias level on the Base while emitter resistor RE sets the output voltage level. Resistor R2 is set as large as possible to prevent loading to the parallel connected crystal. This is a parallel resonant circuit.

Transistors like 2N2222 and 2N3904 work well in this circuit.

Crystal Oscillator Circuits – Page 5

Any general purpose NPN transistor can be used so long as it has an FT of above 100Mhz, well above the crystals fundamental frequency which is usually be between about 5MHz and 25MHz.

The circuit diagram above of the Colpitts Crystal Oscillator circuit shows that capacitors, C1 and C2 shunt the output of the transistor which reduces the feedback signal. Therefore, the gain of the transistor limits the maximum values of C1 and C2. The output amplitude should be kept low in order to avoid excessive power dissipation in the crystal otherwise could destroy itself by excessive vibration.

Another Colpitts Oscillator circuit.


In this circuit, the crystal acts as an inductance. A large value capacitive divider is used between gate, source, and ground, and a small series capacitor is placed in the crystal circuit. You should choose the components values so that? C2 C3 to C1? ratio has the highest possible value. The ratio of 5 to 10 to 1 is usually used.? The schematic shows the typical values. This circuit introduce a little loading on the crystal. The relatively high values of C2 and C3 “swamp out” variations and drift caused by variations in device characteristics. Frequency can be fine tuned with C1. A clean enough sine wave appears at the emitter of the transistor.

Pierce Oscillator

Another common design of the quartz crystal oscillator is that of the Pierce Oscillator. The Pierce oscillator is very similar in design to the previous Colpitts oscillator and is well suited for implementing crystal oscillator circuits using a crystal as part of its feedback circuit.

The Pierce oscillator is primarily a series resonant tuned circuit (unlike the parallel resonant circuit of the Colpitts oscillator) which uses a JFET for its main amplifying device as FET’s provide very high input impedances with the crystal connected between the Drain and Gate via capacitor C1 as shown below.

Crystal Oscillator Circuits – Page 6

Pierce Crystal Oscillator


In this simple circuit, the crystal determines the frequency of oscillations and operates at its series resonant frequency, ƒs giving a low impedance path between the output and the input. There is a 180o
phase shift at resonance, making the feedback positive. The amplitude of the output sine wave is limited to the maximum voltage range at the Drain terminal.

Resistor, R1 controls the amount of feedback and crystal drive while the voltage across the radio frequency choke, RFC reverses during each cycle. Most digital clocks, watches and timers use a Pierce Oscillator in some form or other as it can be implemented using the minimum of components.

Variations in supply voltage, transistor parameters, etc. have no effect on the circuit operating frequency which is held stabilised by the crystal. The circuit frequency stability is set by the crystal frequency stability, which is good. For greater stability, the crystal may be placed in a temperature controlled oven.

OVERTONE CRYSTAL OSCILLATOR

Crystals with an operating frequency of over about 45MHz have been very difficult to achieve because of their very small size. This is overcome by using overtone circuits.

In these circuits the output frequency is three or five times the “cut frequency” of the crystal. This is achieved by having a tuned circuit in the output, tuned to the desired frequency.

This oscillator is designed for overtone crystals, the actual output frequency of the circuit in the 20-100 MHz range operating in the third and fifth mode. Operating frequency is determined by the tuned circuit. Higher order harmonics can be selected to achieve even higher output frequencies.

Crystal Oscillator Circuits – Page 7


Precautions when “driving” crystals

Crystal oscillators must be designed to provide a load capacitance on the crystal as per specifications listed by the manufacturer. This requirement is essential for obtaining oscillations at the specified frequency. It is also important from the point of view of limiting the power supplied to the crystal to the specified maximum. Too much crystal power causes distortion in the oscillator waveform. It also causes overheating of the crystal, consequently rendering the resonant frequency unstable. More important is that the thin-plated electrodes may be melted off an overdriven crystal, destroying the device. Typical maximum drive levels for plated crystals varies from 2 m W to 10 m W.

The maximum permissible drive power limits the ac voltages that may be applied across the crystal and consequently affects the design of oscillator circuits. Crystal manufacturers usually specify the resistance of individual crystal, as well as maximum drive power. From these two, the maximum crystal ac voltage may be determined by using the relation P = V2/R.

Modern small crystals do not usually survive in old style tube oscillator circuits, the drive power is two great and will destroy the crystal very quickly.

Altering the operating frequency

The operating frequency of crystal oscillator can be “pulled or pushed” a very small amount by the use of series or parallel capacitors and or inductors. A capacitor in series will pull the frequency high and a capacitor in parallel will push the frequency low but this is very hard to achieve.

Crystal Oscillator Circuits – Page 8

CMOS Crystal Oscillator

As well as using transistors and FETs, we can also create a simple basic parallel-resonant crystal oscillator similar in operation to the Pierce oscillator by using a CMOS inverter as the gain element. The basic quartz crystal oscillator consists of a single inverting Schmitt trigger logic gate such as the TTL 74HC19 or the CMOS 40106, 4049 types, an inductive crystal and two capacitors. These two capacitors determine the value of the crystals load capacitance. The series resistor helps limit the drive current in the crystal and also isolates the inverters output from the complex impedance formed by capacitor-crystal network.


The crystal oscillates at its series resonance frequency. The CMOS inverter is initially biased into the middle of its operating region by the feedback resistor, R1. This ensures that the Q-point of the inverter is in a region of high gain. Here a 1MΩ value resistor is used, but its value is not critical as long as it is more than 1MΩ. An additional inverter is used to buffer the output from the oscillator to the connected load.

The inverter provides 180o
of phase shift and the crystal capacitor network the additional 180o
required for oscillation. The advantage of the CMOS crystal oscillator is that it will always automatically readjust itself to maintain this 360o
phase shift for oscillation.

Unlike the previous transistor based crystal oscillators which produced a sinusoidal output waveform, as the CMOS Inverter oscillator uses digital logic gates, the output is a square wave oscillating between HIGH and LOW. Naturally, the maximum operating frequency depends upon the switching characteristics of the logic gate used.

Crystal housings

There have been many different housing used to contain crystals used over the years. During the Second World Was millions of FT-243 crystals were produced and these were also extensively used in post War Amateur Radio and two way radio equipment. Here are just a few of the common crystal housing in use today.

Crystal Oscillator Circuits – Page 9


What frequency is written on a crystal ?

Firstly there is often no indication of the mode of operation or the loading capacitance. To make matters worse, many crystals that were used in CB and early Amateur Radio transceivers had the transmit and receive frequency written on them, not the actual oscillating frequency. This was because the local oscillator had to operate at a frequency displaced by the Intermediate Stages frequency. In simple equipment this was usually 455KHz but could have been a much higher frequency, particularly in Amateur radio rigs.

Another factor is these are usually over tone crystals and when tested in a simple crystal tester they will produce their fundamental frequency, not the overtone frequency.

And now for some more technical stuff adapted from -http://www.us-electronics.com/files/crystals.pdf

Quartz is a crystalline form of silicon dioxide (SiO2) which is abundant in nature, forming about 12% of the Earth's crust. A combination of the limited supply of natural quartz along

Crystal Oscillator Circuits – Page 10

with its high cost has resulted in the development of cultured quartz. Crystals of quartz are grown by dissolving SiO2 in an alkaline solution at high temperature and pressure. This process takes place in auto cleaves which are built to withstand the extreme conditions required. Seed crystals are mounted in frames in the cooler part of the autoclave whilst a solution of sodium carbonate or hydroxide and fragments of SiO2 are placed in the warmer portion. The solution moves from the hotter to the cooler region and in doing so, dissolves the nutrient and deposits on the seed crystal. Temperatures are controlled throughout this process.

Large bars of crystal can be grown in about ten weeks. The quality of the quartz depends on the conditions of growth. Crystals are grown in shapes and sizes that minimize wastage of time and material. The bars of crystal are cut into wafers. The angle at which these wafers are cut is crucial in determining the frequency and temperature stability of the final crystal. The most common cut is the AT-cut where the blank is cut from the bar of crystal at approximately 35°, allowing a frequency range of 1MHz to 300MHz.

Since the discovery of the piezoelectric properties of quartz in 1880 by Pierre Curie, quartz has become a significant factor in the growth of the electronics industry. By stretching or compressing a piezoelectric material a voltage is generated. The reverse is also true: a voltage applied to the material causes it to become mechanically stressed. In the case of crystals , the pressure resulting from a voltage being applied is displayed in the form of oscillations at a particular resonant frequency.

The frequency is a function of the thickness of the crystal. By carefully preparing a crystal, it can be made to oscillate at any frequency. The lowest frequency is called the fundamental frequency and can be supplied up to about 45MHz. Higher frequencies (to over 300 MHz) are achieved by operating the crystal at odd overtones (harmonics); 3rd, 5th, 7th, 9th and 11th and tuning the output circuit with an L/C tuned circuit so that the crystal oscillates at its designed overtone frequency.

Overtone crystals are specially processed for plane parallelism and surface finish in order to enhance their performance at the required overtone frequency. The overtone frequency is higher than the equivalent harmonic multiple of the fundamental by approximately 25KHz per overtone.

Vibration modes

The quartz crystal can vibrate in several different ways, and this means that it has several resonances, all on different frequencies. Fortunately the way in which the quartz crystal blank is cut from the original crystal itself can very significantly reduce this. In fact the angle of the faces relative to the original crystal axes determines many of its properties from the way it vibrates to its activity, Q, and its temperature co-efficient. There are three main ways in which a crystal can vibrate: longitudinal mode, low frequency face shear mode, and high frequency shear. A cut known as the AT cut used for most crystals used in traditional radio and electronics circuits uses the high frequency shear mode.

Crystal Oscillator Circuits – Page 11


Vibrational modes of a quartz crystal resonator (For the sake of clarity, the movements have been greatly exaggerated)

You can find detail of how to build a simple crystal tester on my web site at:

http://www.philipstorr.id.au/radio/seven/projects2014.htm

You will need a frequency counter or a modern digital Oscilloscope that has a frequency readout. If you do not need exact accuracy you could use a communications receiver.

This document will be on my web site at:

http://www.philipstorr.id.au/radio/technical/technical.htm

Document - Crystal Techo.pdf by Phil, VK5SRP 26/01/2017

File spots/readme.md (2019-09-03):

# AJ4VD QRSS Spots & Build Log

This page serves is a running log of recent notable QRSS spots. AJ4VD's QRSS signal is transmitted from Gainesville, Florida, USA. 

### 2019-09-02: Spotted in Switzerland
[Bill (W4HBK)](https://www.qsl.net/w4hbk/) emailed the [Knights](https://groups.io/g/qrssknights) a grab of my signal from a KIWI SDR captured at HB9EHO in Ittigen, Switzerland.



### 2019-08-03: Spotted in Sweden
This hint of my transmitter was captured by SA6BSS in Slutarp, Sweden at 12:30AM last night.

Spot | Distance: 4,707 miles
---|---
|

### 2019-07-31: Upgraded Amplifier
The design is similar (CMOS buffer driving an IRF510) but I used perfboard to make this one and placed it in an enclosure. There's no low-pass filter on the amplifier itself, but I put a 30m low-pass filter in-line the coax before the antenna. It's currently outputting 20PPV into 50 ohms (1 watt).

old amplifier | new amplifier
---|---
 | 

Right after hooking it up I saw my signal looking nice on the air:

Ontario, Canada (VA3ROM) | Canary Islands (EA8BVP1)
---|---
|

### 2019-07-30: First Spot Across the Atlantic
It's pretty weak, but you can just make out the unique shape on EA8BVP's grabber in the Canary Islands (4,000 miles away).



### 2019-07-29: Spotted in Canada

I was really strong on VE1VDM's grabber last night, but I found it interesting to see such a strong signal in the middle of the day (11AM).

Nova Scotia, Canada (VE1VDM) | Stack (average of 13 grabs)
---|---
 | 

### 2019-07-26: New SMT PCB oscillator

I swapped-out my Manhattan-style oscillator with a SMT design I'm testing. I was excited to put the SMT connector on there, but in hindsight I should have laid it out sideways because I couldn't close the lid =P




### 2019-07-20: new image stacking software
If the transmitter frequency is stable, transmissions start every 10 minutes, and grabbers are time-aligned to be every 10 minutes, multiple grabs can be averaged together to enhance signal-to-noise ratio. This is called _QRSS Image Stacking_. To simplify the process of making these images I created a new program: [QRSS Stitch and Stack](https://github.com/swharden/QRSS-Stich-and-Stack).

As an aside, the average of 13 images displayed in the screenshot looks great!



### 2019-07-20: started transmitting letters
I finished writing the [microcontroller code](/builds/keyer/) to read the GPS time and only start transmissions when the minutes value ends with a zero. The signal now stacks nicely in 10-minute grabs. Now that GPS and the oven is working well I've started sending my callsign (AJ4VD).

Description | Image
---|---
First AJ4VD identifier spotted in Pensacola, FL (W4HBK) as I was actively adjusting the transmission length | 
AJ4VD spotted in Greensboro, NC (WD4ELG) | 
5x frame stack (mean frame) from the WD4ELG grabber reveals the AJ4VD signal much better, and confirms the GPS timer is working well. | 

### 2019-07-18: OOK and FSK both work now
I got OOK and FSK working together (the S shape in the middle). I'm also now using a cude oven, but am not sure yet how stable frequency is over long timespans.

Description | Image
---|---
AJ4VD spotted in Pensacola, FL (W4HBK) | 
AJ4VD spotted in Greensboro, NC (WD4ELG) | 

I kept thinking my oscillator was drifting frequency because the line wasn't straight. Turns out it was my curved monitors =P



### 2019-07-14: amplifier improvements

I improved my amplifier (now output 500mW) and am impressed how well my attic dipole is doing! It runs east/west so it radiates north/south. I saw my signal on a few more grabbers.

Description | Image
---|---
AJ4VD spotted in Northwood, OH (N8NJ) | 
AJ4VD spotted in Las Cruces, NM (WA5DJJ) | 
AJ4VD spotted in Florida (WD4AH) with a nice airplane reflection in the middle | 
AJ4VD spotted in Ontario, Canada | 
AJ4VD spotted in Pensacola, FL (W4HBK) but this 8-hour grab reveals when my AC kicks on and off and demonstrates the necessity of ovenizing my setup. It's the signal around 10,139,980 Hz. | 

### 2019-07-13: first QRSS transmissions (in a few years)

This week I strung-up a 30m dipole in the attic and built an oscillator, keyer, and amplifier (all as separate modules). I finished the amplifier this morning and spotted the signal (the rectangular squiggle) on two grabbers. I was running 3 PPV into 50 Ohm so I think that's about 22 mW.

Description | Image
---|---
AJ4VD spotted in Pensacola, FL (W4HBK) | 
AJ4VD spotted in Greensboro, NC (WD4ELG) | 

### Historical QRSS Experiments
See [/history/](/history/) for a notes regarding AJ4VD's earlier QRSS experiments.

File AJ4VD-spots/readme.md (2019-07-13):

# AJ4VD QRSS Spots

This page serves is a running log of notable QRSS spots. AJ4VD's QRSS signal is transmitted from Gainesville, Florida, USA.

### 2019-07-13

This week I strung-up a 30m dipole in the attic and built an oscillator, keyer, and amplifier (they're all separate modules because I intend to tinker with them individually). I finished the amplifier this morning and spotted the signal (the rectangular squiggle) on two grabbers.

Description | Image
---|---
oscillator (colpitts / varactor) | 
keyer (ATTiny2313) | 
amplifier (IRF510 class C) | 
spotted in Pensacola, FL (W4HBK) | 
spotted in Greensboro, NC (WD4ELG) | 

# History of AJ4VD and QRSS

**Discovering QRSS (Mar, 2009):** I first noted interest in QRSS on my website in March, 2009 when I cited [a page](https://web.archive.org/web/20100107204201/http://g4oep.atspace.com/qrss/qrss.htm) summarizing the topic. I had no experience in radio at the time. I ordered a VHF radio that month and got a technician radio license in April, 2009. In May I used a can oscillator to generate a 28MHz signal I could pick up with my FM radio scanner a few thousand feet away.

**QRSS Capture (Dec, 2009):** I captured my first QRSS signal in Dec 2009. It was Dave Hassall (WA5DJJ) and I was thrilled because I had seen [his website](http://www.zianet.com/dhassall/) before. I got my callsign (KJ4LDF at the time) added to [his spotters list](http://www.zianet.com/dhassall/QRSSMILES.html).

**Spectrograph software (March, 2010):** Since I had limited antenna space, little knowledge, and no general-class radio license, I channeled my interest in QRSS into learning more about its reception by writing analysis software. I first noted developing a spectrograph in March, 2010 (during dental school spring break). That project later matured into [QRSS-VD](https://github.com/swharden/QRSS-VD).

**First QRSS Spot (May, 2010):** I wish I documented this better! My first QRSS spot used the CKOUT signal of a microcontroller clocked at 10.140MHz to trigger a line driver fed directly into a wire antenna on the ceiling of my apartment. I am guessing this was May 2010. It took no time for me to start using the microcontroller to drive a varactor diode to frequency-shift the signal in annoying ways. The QRSS gator on May 27, 2010 is my first spot (received in in MA, satisfyingly by somebody using QRSS-VD software). While I used my own transmitter design (~100mW) I had a lot of help getting the signal out using UF's amateur radio club station (W4DFU) antenna (an 80m dipole at 120 ft).



**Hiatus (Aug, 2011):** I actively experimented with QRSS almost every day until August, 2011 when a large change in my personal life led me to put the hobby down. As part of a move I boxed-up all my electronics equipment, and I never got around to pulling it out. I broke-out some equipment in 2013 and again in 2015 with the goal of building an ovenized transmitter, but got so distracted with temperature regulation (both times) that I burned out before I ever made anything meaningful.

**QRSS Plus (July, 2013):** Although I didn't keep-up experimenting with QRSS _hardware_ for several years, I quietly followed the QRSS mailing lists. I noticed that a huge amount of posts were people saying, "I just turned on my grabber", or "my grabber is going offline" and I thought it would be useful to make an automatically-updating active QRSS grabber list. I called the project [QRSS Plus](http://swharden.com/qrss/plus/) I first implemented it entirely in PHP in July 2013. I recoded the back-end in Python in 2016, and the front-end is still PHP. I'm proud that QRSS Plus has been continuously running since 2013!

**AJ4VD is back? (July, 2019):** During my QRSS hiatus I continued to work on software and hardware projects. Although none of them were in the RF/QRSS world, getting back into this hobby was always been in the back of my mind. Medical issues (chemotherapy / bone marrow transplant) made me stop everything for about 6 months (including a month I lived in the hospital), but after that I found myself being drawn back into the QRSS hobby. I strung-up an attic antenna, a QRSS transmitter, and spotted the signal on July 13. We will see where it goes from here...

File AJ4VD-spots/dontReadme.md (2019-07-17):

# AJ4VD QRSS Spots

This page serves is a running log of notable QRSS spots. AJ4VD's QRSS signal is transmitted from Gainesville, Florida, USA.

### 2019-07-14
I improved my amplifier and now output closer to 500mW. I think my new attic dipole (aimed north) is doing a fantastic job! We can add two new locations to the list.

Description | Image
---|---
AJ4VD spotted in Northwood, OH (N8NJ) | 
AJ4VD spotted in Las Cruces, NM (WA5DJJ) | 
AJ4VD spotted in Florida (WD4AH) | 
AJ4VD spotted in Ontario, Canada | 

### 2019-07-13

This week I strung-up a 30m dipole in the attic and built an oscillator, keyer, and amplifier (they're all separate modules because I intend to tinker with them individually). I finished the amplifier this morning and spotted the signal (the rectangular squiggle) on two grabbers. I was running 3 PPV into 50 Ohm so I think that's about 22 mW.

Description | Image
---|---
oscillator (colpitts / varactor) | 
keyer (ATTiny2313) | 
amplifier (IRF510 class C) | 
AJ4VD spotted in Pensacola, FL (W4HBK) | 
but temperature drift is pretty lousy... better build an oven! | 
AJ4VD spotted in Greensboro, NC (WD4ELG) | 

# History of AJ4VD and QRSS

**Discovering QRSS (Mar, 2009):** I first noted interest in QRSS on my website in March, 2009 when I cited [a page](https://web.archive.org/web/20100107204201/http://g4oep.atspace.com/qrss/qrss.htm) summarizing the topic. I had no experience in radio at the time. I ordered a VHF radio that month and got a technician radio license in April, 2009. In May I used a can oscillator to generate a 28MHz signal I could pick up with my FM radio scanner a few thousand feet away.

**QRSS Capture (Dec, 2009):** I captured my first QRSS signal in Dec 2009. It was Dave Hassall (WA5DJJ) and I was thrilled because I had seen [his website](http://www.zianet.com/dhassall/) before. I got my callsign (KJ4LDF at the time) added to [his spotters list](http://www.zianet.com/dhassall/QRSSMILES.html).

**Spectrograph software (March, 2010):** Since I had limited antenna space, little knowledge, and no general-class radio license, I channeled my interest in QRSS into learning more about its reception by writing analysis software. I first noted developing a spectrograph in March, 2010 (during dental school spring break). That project later matured into [QRSS-VD](https://github.com/swharden/QRSS-VD).

**First QRSS Spot (May, 2010):** I wish I documented this better! My first QRSS spot used the CKOUT signal of a microcontroller clocked at 10.140MHz to trigger a line driver fed directly into a wire antenna on the ceiling of my apartment. I am guessing this was May 2010. It took no time for me to start using the microcontroller to drive a varactor diode to frequency-shift the signal in annoying ways. The QRSS gator on May 27, 2010 is my first spot (received in in MA, satisfyingly by somebody using QRSS-VD software). While I used my own transmitter design (~100mW) I had a lot of help getting the signal out using UF's amateur radio club station (W4DFU) antenna (an 80m dipole at 120 ft).



**Hiatus (Aug, 2011):** I actively experimented with QRSS almost every day until August, 2011 when a large change in my personal life led me to put the hobby down. As part of a move I boxed-up all my electronics equipment, and I never got around to pulling it out. I broke-out some equipment in 2013 and again in 2015 with the goal of building an ovenized transmitter, but got so distracted with temperature regulation (both times) that I burned out before I ever made anything meaningful.

**QRSS Plus (July, 2013):** Although I didn't keep-up experimenting with QRSS _hardware_ for several years, I quietly followed the QRSS mailing lists. I noticed that a huge amount of posts were people saying, "I just turned on my grabber", or "my grabber is going offline" and I thought it would be useful to make an automatically-updating active QRSS grabber list. I called the project [QRSS Plus](http://swharden.com/qrss/plus/) I first implemented it entirely in PHP in July 2013. I recoded the back-end in Python in 2016, and the front-end is still PHP. I'm proud that QRSS Plus has been continuously running since 2013!

**Will AJ4VD be back? (July, 2019):** During my QRSS hiatus I continued to work on software and hardware projects. Although none of them were in the RF/QRSS world, getting back into this hobby was always been in the back of my mind. Medical issues (chemotherapy / bone marrow transplant) made me stop everything for about 6 months (including a month I lived in the hospital), but after that I found myself being drawn back into the QRSS hobby. I strung-up an attic antenna, a QRSS transmitter, and spotted the signal on July 13. We will see where it goes from here...

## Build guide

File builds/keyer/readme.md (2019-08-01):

# QRSS Keyer

I'd like to use an interesting pattern that takes advantage of both FSK and OOK. I want it to be 5 Hz or less in bandwidth, and I want it to be unique and recognizable in cases where only a few seconds are spotted, but I don't want it to be so odd that it's annoying. I came up with something like:



Here's what it looks like on the air:

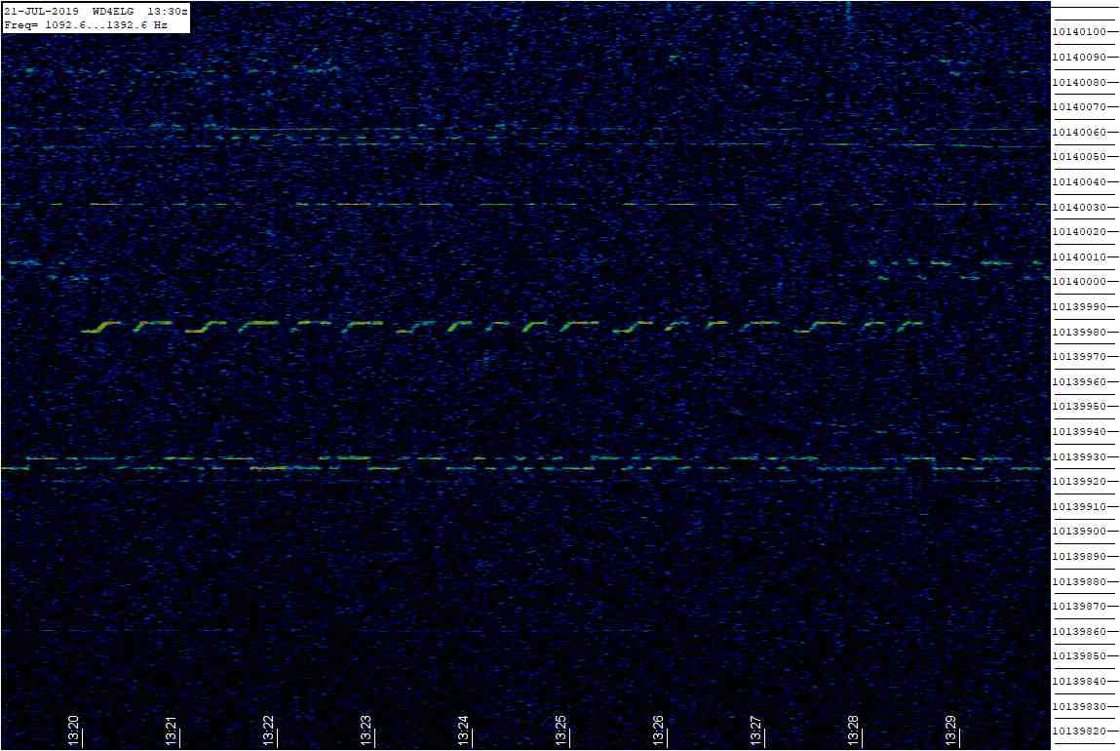
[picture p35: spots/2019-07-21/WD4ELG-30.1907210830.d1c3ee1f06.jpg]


## Design
 
### Microcontroller
ATTiny2313 programmed with C ([source code](main.c))

### GPS serial data parsing
To ensure the message transmits exactly at the 0:00 mark of every 10 minutes, the microcontroller is occasionally put into a "wait" mode where it continuously watches the GPS output (parsing the serial data that bursts out every second) and waits for the minutes digit to become zero before beginning a transmission.

Technical details: The output is 9600 baud serial data in [NMEA format](https://www.gpsinformation.org/dale/nmea.htm). A string buffer is filled as incoming characters are received. If the message starts with `$GPRMC` we know the 11th character is the ones digit of the minutes number in the time code. Waiting for the next ten minute rollover to occur is as easy as waiting until that character becomes zero.

```
$GPRMC,184130.00,...
^    ^     ^
```

The start of a time message looks like this. To identify `$GPRMC` we just need to match the `$` and the `C` (indicated by the first two arrows above). We then know if we keep reading, we will arrive at the ones digit of the minutes number (the third arrow).

I have some notes on the [Neo-6M here](https://github.com/swharden/AVR-projects/tree/master/uBlox%20Neo-6M)

### FSK Circuit

I found this design very convenient. A potentiometer (RV1) sets center frequency to let me adjust where in the QRSS band I want to transmit. 

The FSK input (which could be digital or analog) is 0-5V, expected to originate from a microcontroller pin. The keyer is programmed to transmits over the full 0-5V range.

The second potentiometer (RV2) sets the width of the FSK input. I adjust this to achieve a bandwidth of about 5 Hz.

The output is buffered, mixed, and sent to the oscillator module with coax.

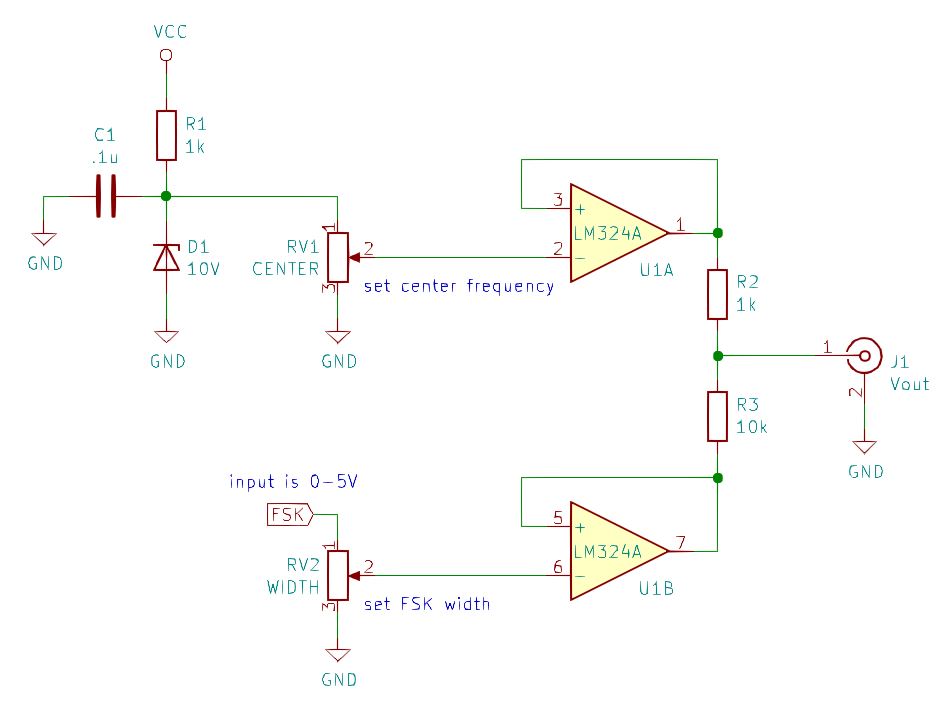
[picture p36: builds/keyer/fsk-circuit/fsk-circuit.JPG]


### Photos


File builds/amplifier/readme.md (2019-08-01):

# QRSS Amplifier

I built a crude amplifier just to get on the air. It outputs about 1W and uses an IRF510 final stage (class C). It also accepts an on-off-keying (OOK) signal (amplifier output is disabled when this line is high).

If the output inductor were wound as a transformer, this circuit could handle much more power output.


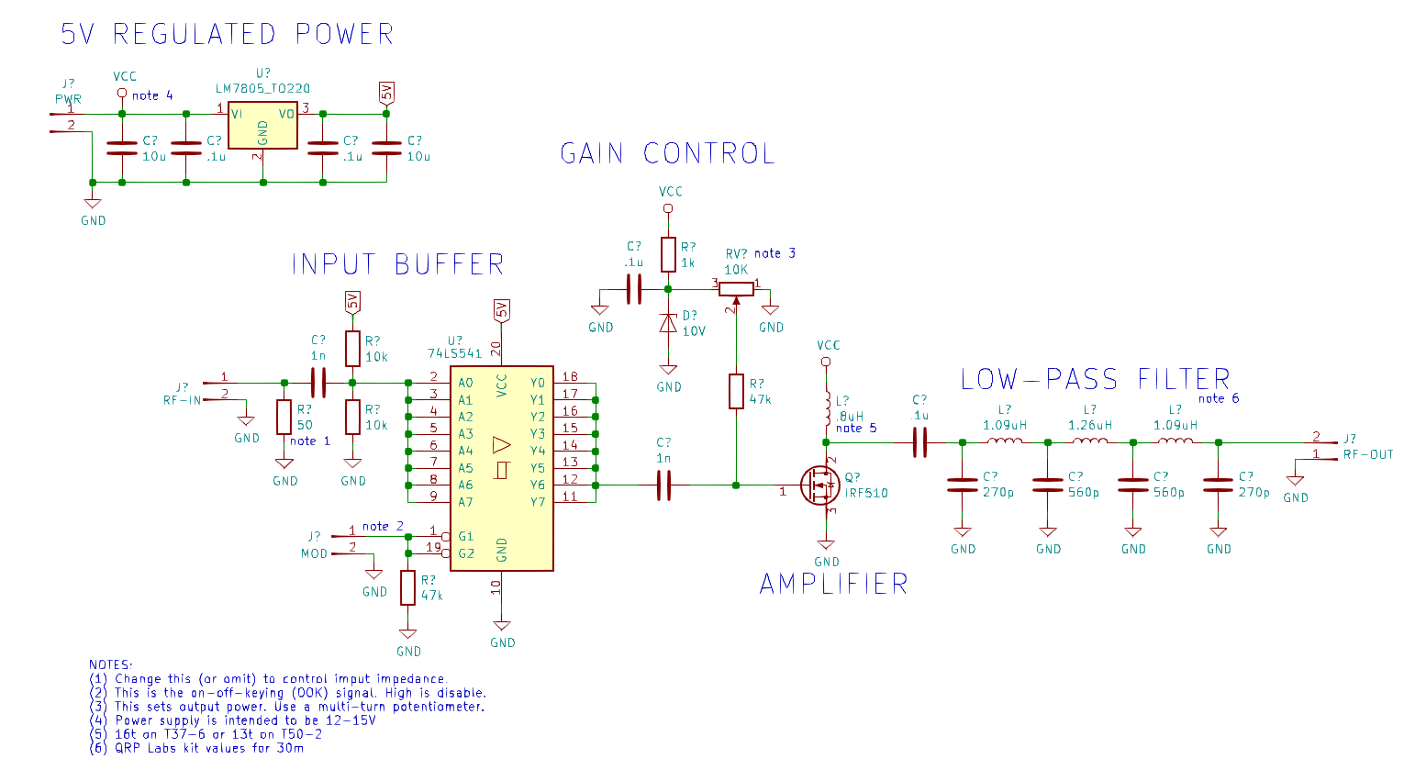
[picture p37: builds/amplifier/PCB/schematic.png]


### Class C Notes

* Inductor values for 50 Ohms impedance at 10.14 MHz
  * 13 turns on a T50-2 is 0.83 uH (52.8 Ohms)
  * 16 turns on a T37-6 is 0.77 uH (48.9 Ohms)
* A SMT [82 uH (300 mA) inductor](https://www.mouser.com/ProductDetail/Wurth-Elektronik/7447669182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) 4532 ($0.39) could be nice
* ~~[IRF510](https://www.mouser.com/ProductDetail/Vishay-Siliconix/IRF510SPBF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) TO-263-3 ($1.23)~~
  * Use smaller transistors/FETs for finals. 
  * IRF510 has high gate capacitance and is has more power than QRSS needs.

### Lowpass filter

#### Quick and dirty 3-pole

According to the [Chebyshev Calculator](http://www.calculatoredge.com/electronics/ch%20pi%20low%20pass.htm): 

* C1 and C2 = 200 pF
* L1 = 761 nH (16t on T37-6)

#### QRP Labs 5-pole
I had one of [these](https://www.qrp-labs.com/images/lpfkit/assembly_A4.pdf) around so I made an in-line filter module for 30m.

* L2 = 20t on T37-6 (1.26 uH)
* L1 and L3 = 19t on T37-6 (1.09 uH)
* C1 and C4 = 270
* C2 and C3 = 560



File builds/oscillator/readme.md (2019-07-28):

# QRSS Oscillator

This page documents development of a voltage-controlled oscillator suitable for QRSS. The oscillator project is developed in concert with the oven project.

## Varactor FSK Designs for QRSS

For QRSS it's convenient to have 2 frequency shift adjustments: a coarse one to set frequency (~200 Hz), and a fine one for FSK (5 Hz). 

Most QRSS TX designs use a variable capacitor to set the coarse adjustment, but I don't like that design because it means you have to open your enclosure every time you want to shift frequency:



VK2ZAY shows a design that pulls one leg of a crystal using two varactors, the magnitude of each is controlled by a series capacitor:



I tried building designs like this I find them very frustrating. 

Issue 1: coarse adjustment modifies FSK shift.
Every time I adjust the coarse voltage, the FSK distance changes. Consider a coarse adjustment resulting in a small capacitance: the fine FSK can produce a large shift. When the coarse produces a large capacitance, the fine FSK has little effect. If your fine FSK is a perfect 5Hz and you adjust the coarse frequency, your FSK is no longer 5Hz.

Issue 2: ~varactor diodes are too variable at low voltages. For stable operation it helps to run a varactor at several volts. I fix this by running the FSK voltage through a voltage divider _to VCC_ (not ground), and use the high-pulled fractional voltage on the varactor.~ Actually this was only a problem for reverse-biased LEDs. Real varactor diodes worked fine at low voltages.

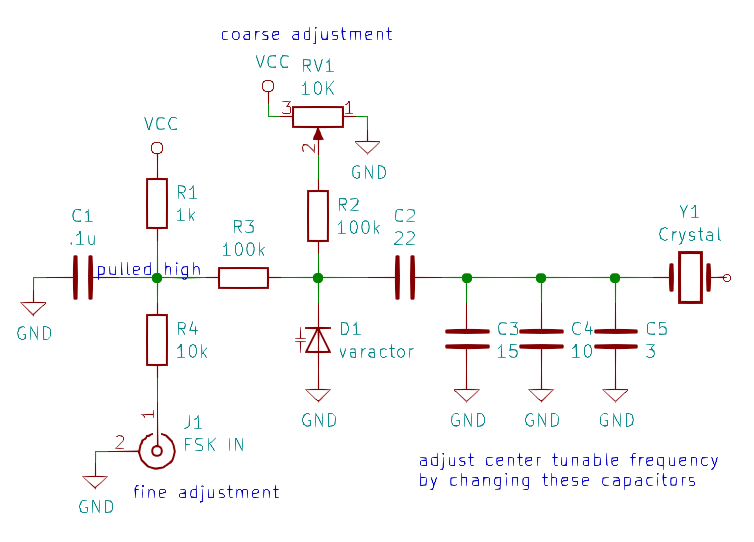
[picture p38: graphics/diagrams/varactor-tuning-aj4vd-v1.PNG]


***NOTE TO SELF: Use a real varicap diode! You have [BB132](https://uk.rs-online.com/webdocs/0466/0900766b80466490.pdf) (around 60 pF) and [BB149A](http://pdf.datasheetcatalog.com/datasheet/NXP_Semiconductors/BB149A.pdf) (around 20 pF) so you can get tons of swing by using one! Stop using reverse-biased LEDs!*** A reverse-biasd blue LED measured 60 Hz swing (with a lot of additional fixed capacitance in place to get near center frequency). Replacing this with a BB132 (I had to remove a 5pA cap to compensate) I got a swing of 159 Hz. That's more than double, and that's just one varicap. You can stack them in parallel. **Real varicaps dont mind low voltage*** I found out, so don't worry about avoiding that super low region like with the LED.

This is a design I came up with that seems to be treating me well so far. Fixed capacitors (optionally populated) set the frequency so the crystal oscillates in the QRSS band. The coarse adjustment moves the signal around the QRSS band (100Hz). The fine adjustment is pulled high through a divider. Adjust R4 to control how wide the FSK can be.

## QRSS Oscillator Revision 1.1

### Design
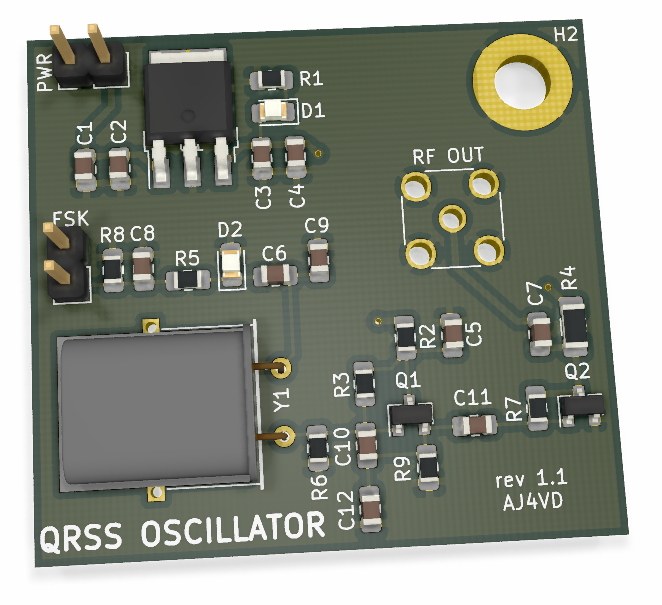
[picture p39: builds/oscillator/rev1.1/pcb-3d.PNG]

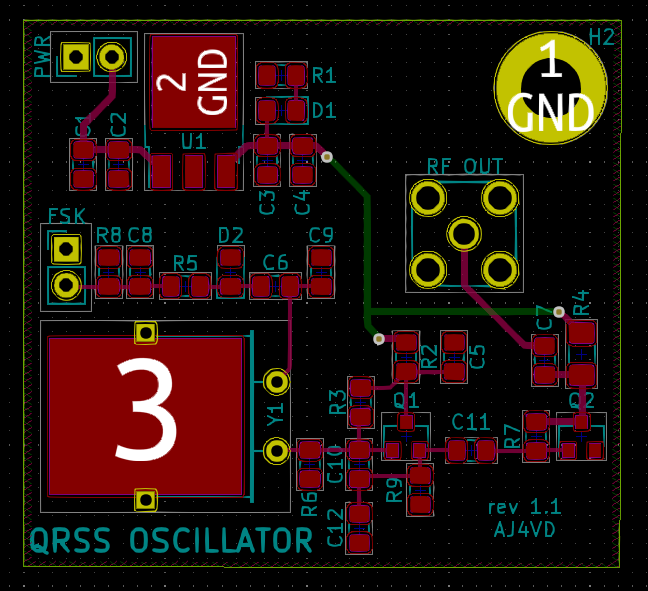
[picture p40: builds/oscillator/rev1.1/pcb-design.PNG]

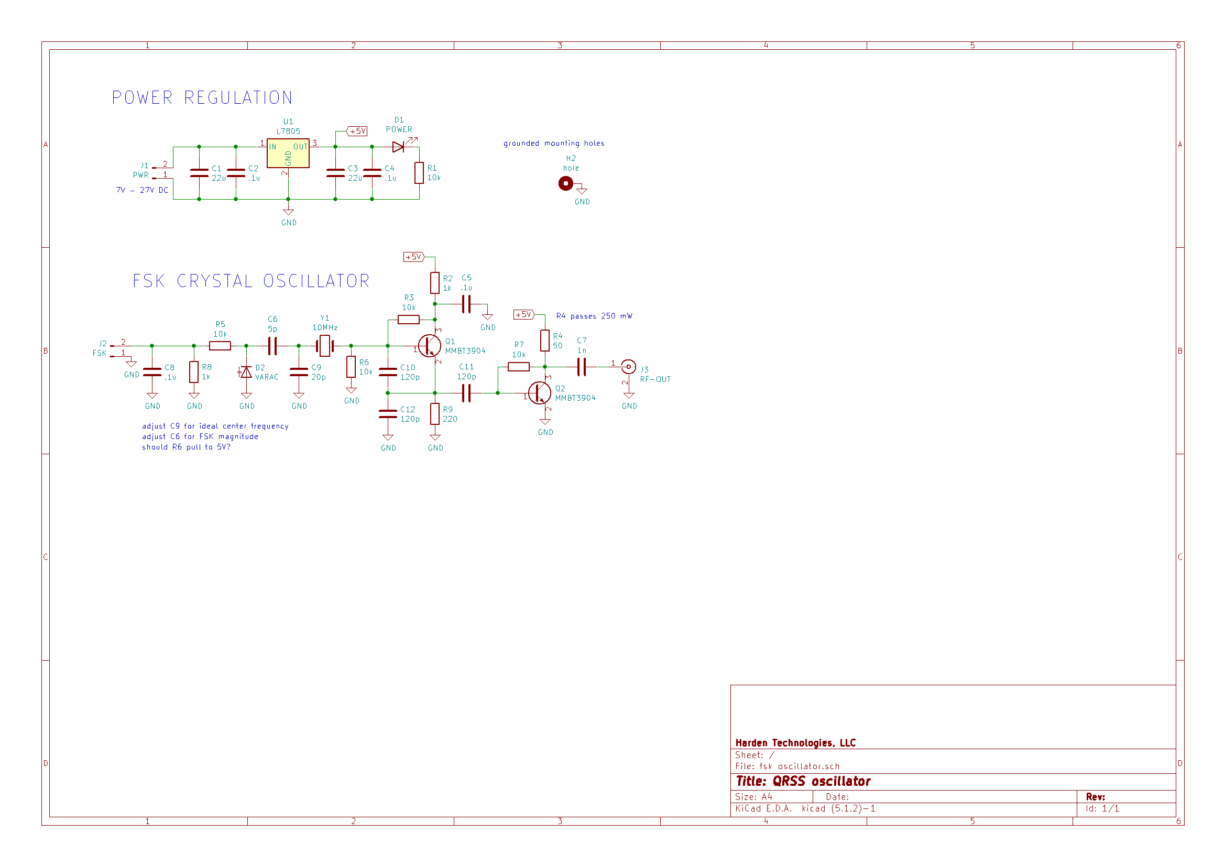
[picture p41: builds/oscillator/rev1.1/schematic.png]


### Build Notes

* I used BB132 for the varicap
* I used 33P for C6
* For C9 I used 33p (should be NP0)
* For C11 I used 100p
* For C10 and C12 I used NP0 120p caps

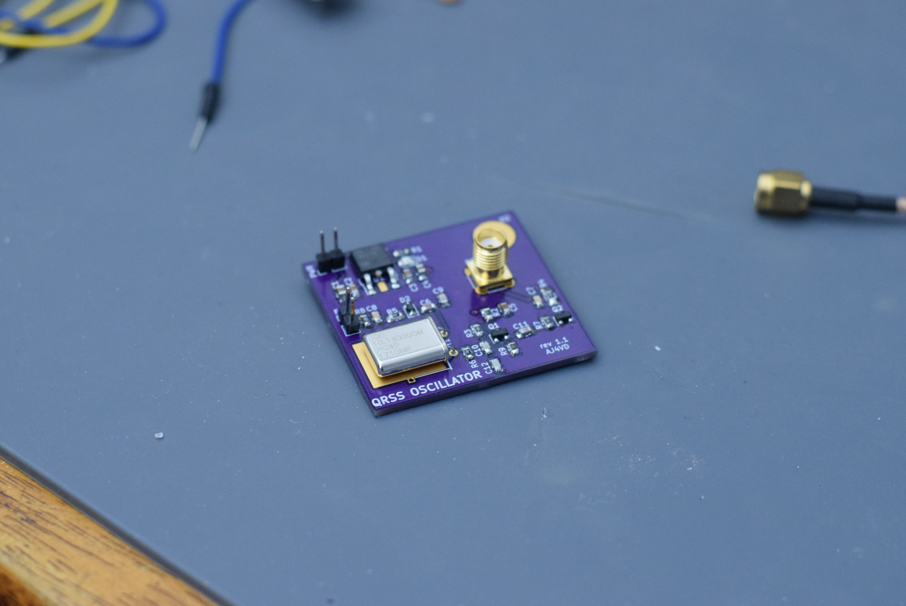
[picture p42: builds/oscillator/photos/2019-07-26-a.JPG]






## QRSS Oscillator Revision 1.2

This version has the oven built into the PCB.
The oven controller is still external.
Not sure how many resistors need to actually be populated for the oven.
I ordered this PCB on 2019-07-28.

### Design

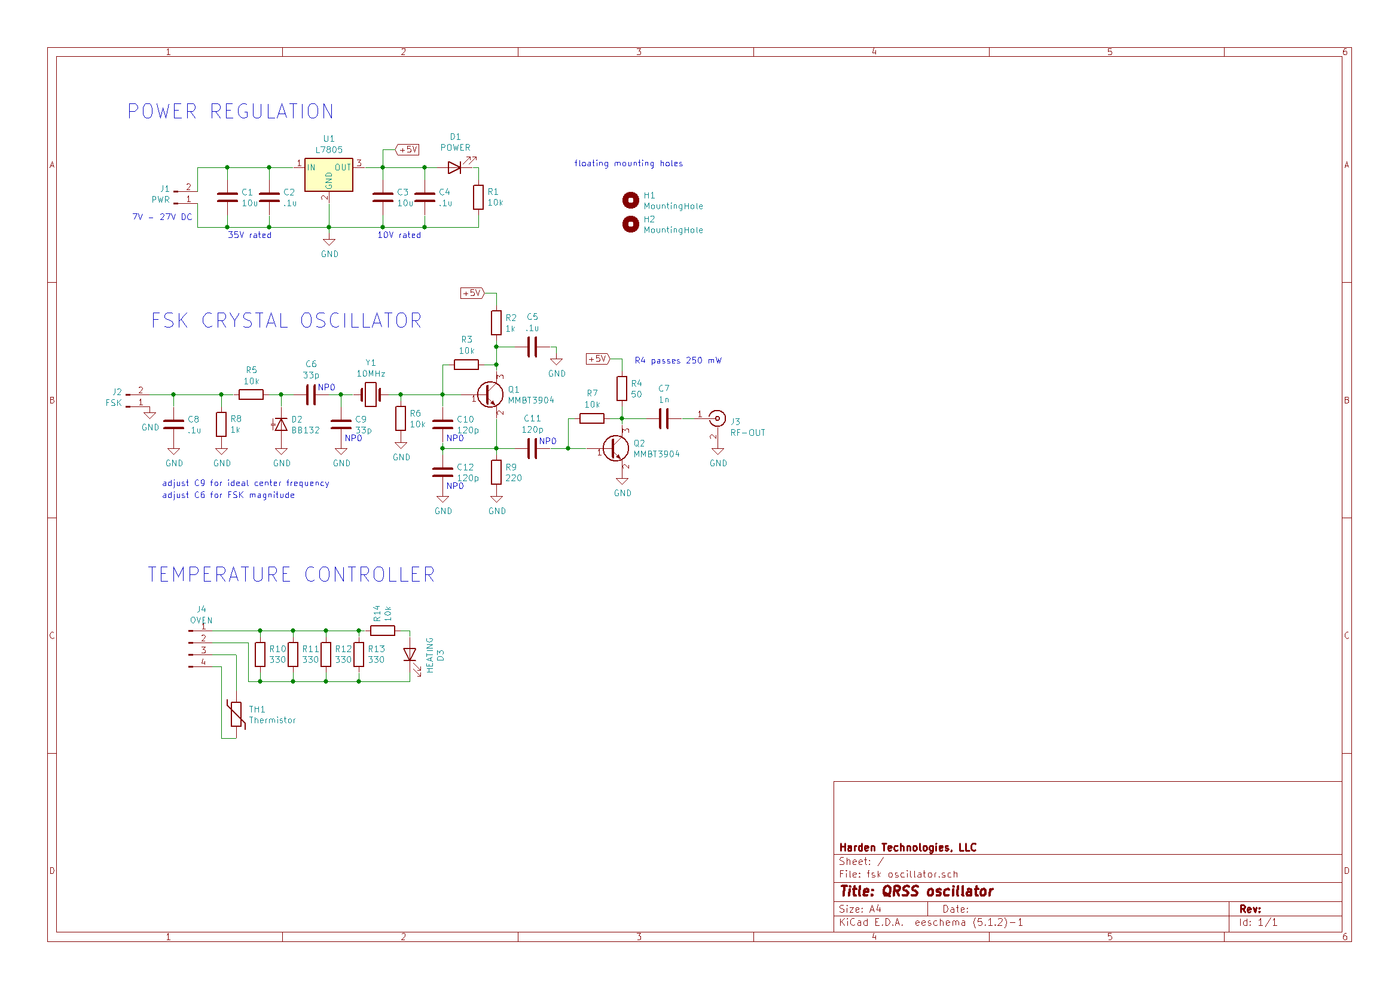
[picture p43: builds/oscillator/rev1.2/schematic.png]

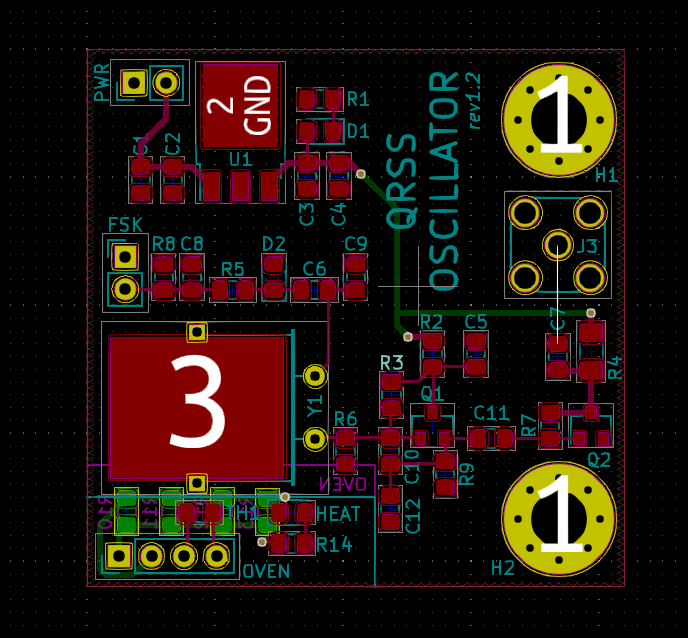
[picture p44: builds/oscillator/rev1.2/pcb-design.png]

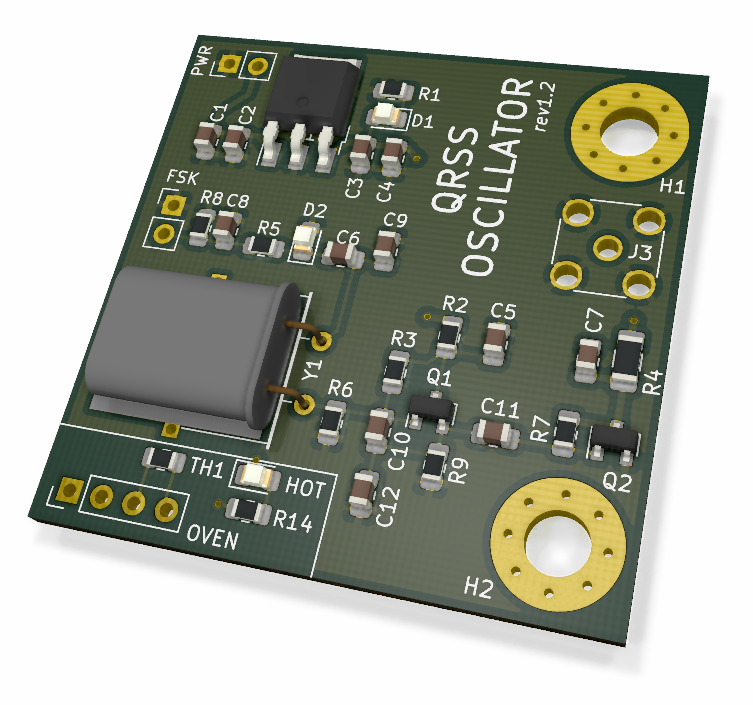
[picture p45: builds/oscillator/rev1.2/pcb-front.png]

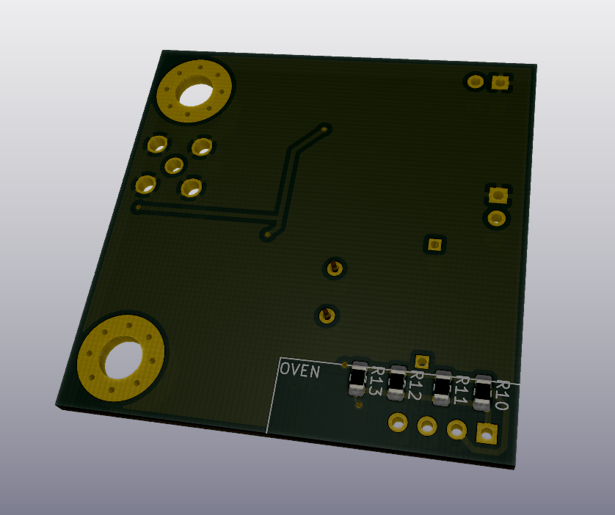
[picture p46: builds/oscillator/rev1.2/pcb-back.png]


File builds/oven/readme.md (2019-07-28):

# QRSS Oven

### QRSS Oscillators Need Ovens
My oscillator looks stable on time scales of minutes, but on time scales of hours it is obvious that it wobbles as my central air conditioning turns on and off. I could go nuts with Styrofoam, but a crystal oven (or chassis heater) is warranted.

### Why I want a chassis heater (not a oven heater)
Some DIY QRSS ovens use resistors as the heater element and package the heater and temperature sensor against the crystal. While temperature stability of the crystal is good, I prefer to thermo-stabilize all frequency-determining components (capacitors and varactors) of the oscillator circuit. For this reason, I prefer a chassis heater.

### Eventually I want a SMT PCB heater
When I get an oscillator I like using SMT parts, I'll try adding the temperature sensor and heater directly on the board. This is ideal for small PCBs. It would be cool if the board could thermo-regulate itself, then the oscillator would just need insulation, and the heater would require very low power.

### Chassis Heater Design
* see [chassis heater designs and experiments](2019-07-15%20chassis%20heater) 

### Calculating power dissipation of a transistor heating a resistor

Consider a NPN with a collector tied to VCC (`Vcc`) and emitter dumping into a resistor (`R`) to ground. Let's say I'm driving a 50 Ohm resistor as a heater. How hot will the transistor get? Is my transistor beefy enough? To answer this I need to ***determine the peak power dissipation through a transistor into a resistive load.***

We should assume the current flowing through the resistor (`I`) will be the same as the current flowing through the transistor.

```c
// Ve is a function of R and I
Ve = R * I

// transistor voltage drop
Vce = Vcc - Ve

// power through the transistor
Pnpn = I * Vce

// substitute 
Pnpn = I * Vce
Pnpn = I * (Vcc - Ve)
Pnpn = I * (Vcc - (R * I))
Pnpn = (I * Vcc) - (I^2 * R)

// at peak power the first derivative of current is zero
Pnpn = (I * Vcc) - (I^2 * R)
d(Pnpn) = Vcc - (2 * I * R) = 0

// find the current through the resistor (= transistor) at peak power
Vcc - (2 * I * R) = 0
2 * I * R = VCC
Ipeak = VCC / (2 * R)

// substitute back into original equation
Pnpn = (Ipeak * Vcc) - (Ipeak^2 * R)
Pnpn = ((Vcc / (2 * R)) * Vcc) - ((Vcc / (2 * R))^2 * R)
Pnpn = (Vcc^2) / (2 * R) - (Vcc^2 * R) / (4 * R^2)
4 * R * Pnpn = 2 * Vcc^2 - Vcc^2
Pnpn = Vcc ^ 2 / (4 * R)
Pnpn = Vcc * Vcc / (4 * R)
Pnpn = Vcc * (I * R) / (4 * R)
Pnpn = Vcc * I / 4

// since the power through the resistor is
Pr = Vcc * I

// peak power through the NPN is 1/4 that through the resistor
Pnpn = Vcc * I / 4
```

* If I drop 12V through a 330 Ohm resistor it passes 36.4 mA of current and dissipates 436.4 mW of power. This means the transistor will dissipate 109 mW of power at its max. 
  * A 2n7000 can handle this.
  * A [0.5W 0805 300 Ohm resistor](https://www.mouser.com/ProductDetail/Panasonic/ERJ-P06J331V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) can handle this (Mouser # 667-ERJ-P06J331V)

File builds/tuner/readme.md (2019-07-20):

# QRP Antenna Tuner for QRSS
(I haven't made this yet)

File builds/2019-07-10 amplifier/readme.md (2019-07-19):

# QRSS Amplifier

## Quick and dirty amplifier

I built a crude amplifier just to get on the air. It outputs about 1W and uses an IRF510 final stage (class C). It's bad. I won't even show the schematic.

## Notes

### Class C Inductor Values
* Inductor values for 50 Ohms impedance at 10.14 MHz
  * 13 turns on a T50-2 is 0.83 uH (52.8 Ohms)
  * 16 turns on a T37-6 is 0.77 uH (48.9 Ohms)
  
Could something like this work?
* [82 uH (300 mA) inductor](https://www.mouser.com/ProductDetail/Wurth-Elektronik/7447669182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) 4532 ($0.39)
* ~~[IRF510](https://www.mouser.com/ProductDetail/Vishay-Siliconix/IRF510SPBF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) TO-263-3 ($1.23)~~

No, use discrete smaller transistors/FETs for finals. The inductor could work.

### Lowpass filter
[Chebyshev Pi LC Low Pass Filter Calculator](http://www.calculatoredge.com/electronics/ch%20pi%20low%20pass.htm)

* 3-pole low-pass filter
  * C1 and C2 = 200 pF
  * L1 = 761 nH (16t on T37-6)

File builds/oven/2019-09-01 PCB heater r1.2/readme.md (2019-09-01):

# PCB Heater r1.2

The ultimate goal is to create a thermo-stable oscillator by heating the PCB to above ambient temperature (about 120F). This board tests how effective 8x 330 Ohm resistors can be at heating a 5cm x 5cm PCB. 

* A 10K NTC thermistor senses temperature in the center of the board
* At 12V each 330 Ohm resistor passes 36.3 mA (437 mW)
* Total max heating power is around 3.5 W
* The transistor also serves as a heating element

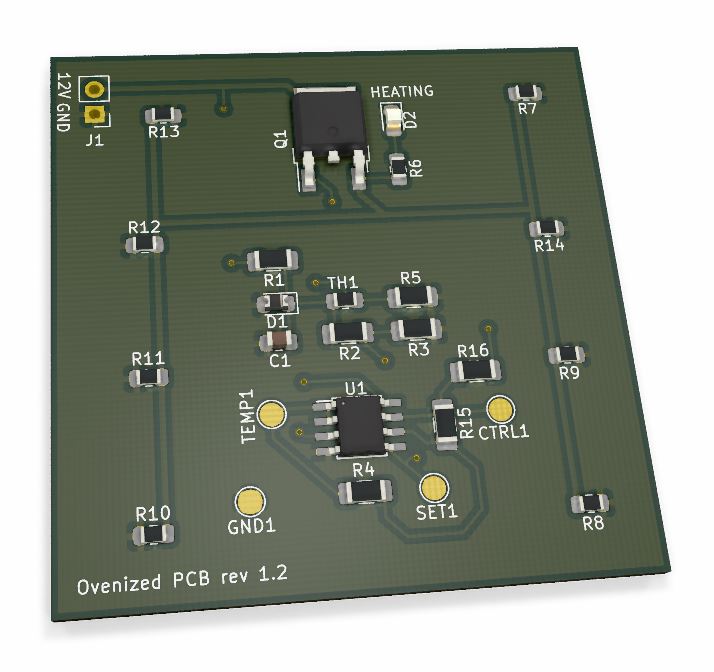
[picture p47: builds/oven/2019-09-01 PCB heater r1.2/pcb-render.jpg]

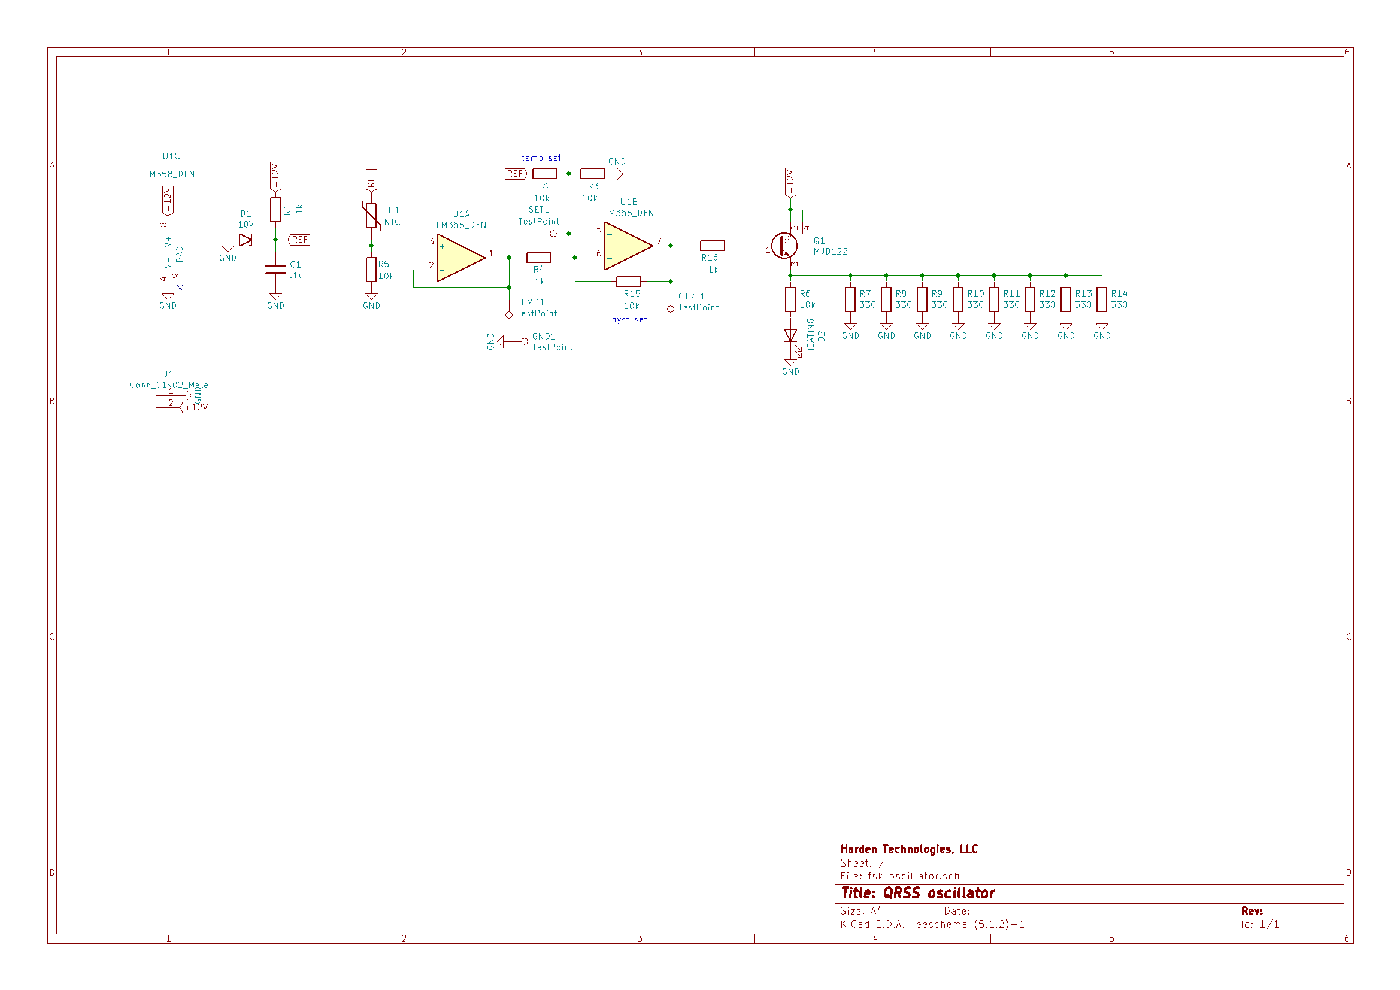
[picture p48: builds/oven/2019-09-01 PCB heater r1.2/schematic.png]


## Build Notes

_I ordered this board on 2019-09-01_

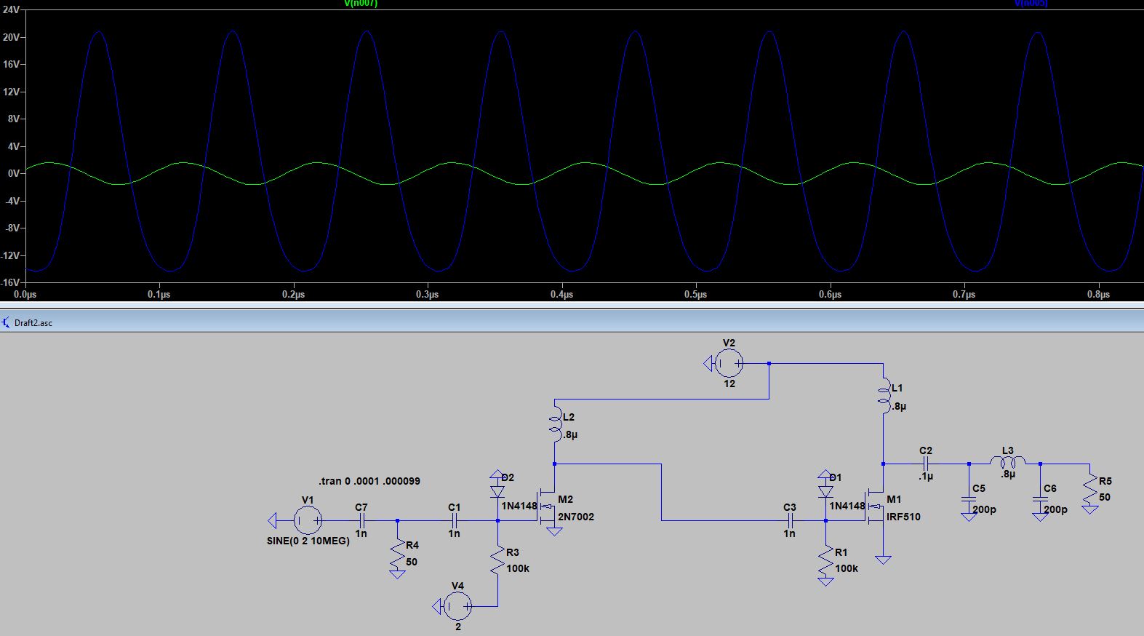
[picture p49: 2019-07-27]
builds/amplifier/LTspice/Draft2.jpg

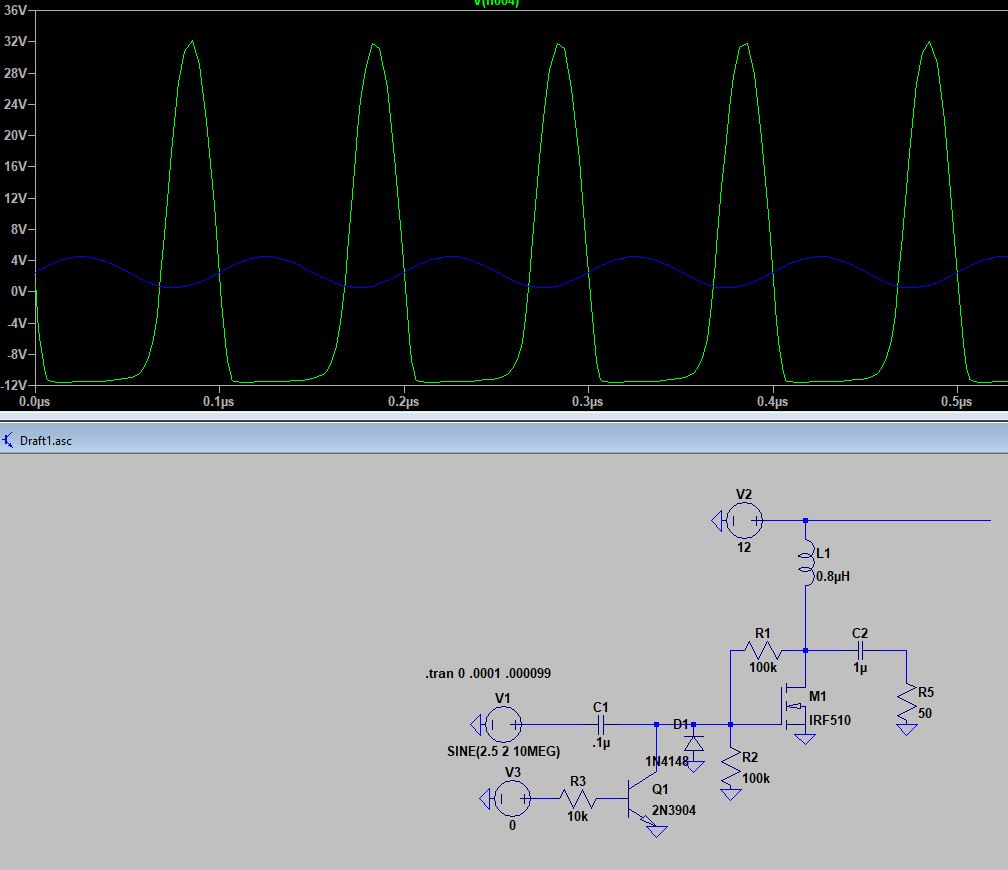
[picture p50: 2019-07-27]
builds/amplifier/LTspice/Draft1.jpg

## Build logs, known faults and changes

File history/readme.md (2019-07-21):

# History of AJ4VD and QRSS

_This history evolves as I find old images and notes. I'm collecting those details here because it will eventually form am "about" page._

**Discovering QRSS (Mar, 2009):** I first noted interest in QRSS on my website in March, 2009 when I cited [a page](https://web.archive.org/web/20100107204201/http://g4oep.atspace.com/qrss/qrss.htm) summarizing the topic. I had no experience in radio at the time. I ordered a VHF radio that month and got a technician radio license in April, 2009. In May I used a can oscillator to generate a 28MHz signal I could pick up with my FM radio scanner a few thousand feet away.

**QRSS Capture (Dec, 2009):** I captured my first QRSS signal in Dec 2009. It was Dave Hassall (WA5DJJ) and I was thrilled because I had seen [his website](http://www.zianet.com/dhassall/) before. I got my callsign (KJ4LDF at the time) added to [his spotters list](http://www.zianet.com/dhassall/QRSSMILES.html).

**Spectrograph software (March, 2010):** Since I had limited antenna space, little knowledge, and no general-class radio license, I channeled my interest in QRSS into learning more about its reception by writing analysis software. I first noted developing a spectrograph in March, 2010 (during dental school spring break). That project later matured into [QRSS-VD](https://github.com/swharden/QRSS-VD).

**First QRSS Spot (May, 2010):** I wish I documented this better! My first QRSS spot used the CKOUT signal of a microcontroller clocked at 10.140MHz to trigger a line driver fed directly into a wire antenna on the ceiling of my apartment. I am guessing this was May 2010. It took no time for me to start using the microcontroller to drive a varactor diode to frequency-shift the signal in annoying ways. The QRSS gator on May 27, 2010 is my first spot (received in in MA, satisfyingly by somebody using QRSS-VD software). While I used my own transmitter design (~100mW) I had a lot of help getting the signal out using UF's amateur radio club station (W4DFU) antenna (an 80m dipole at 120 ft).

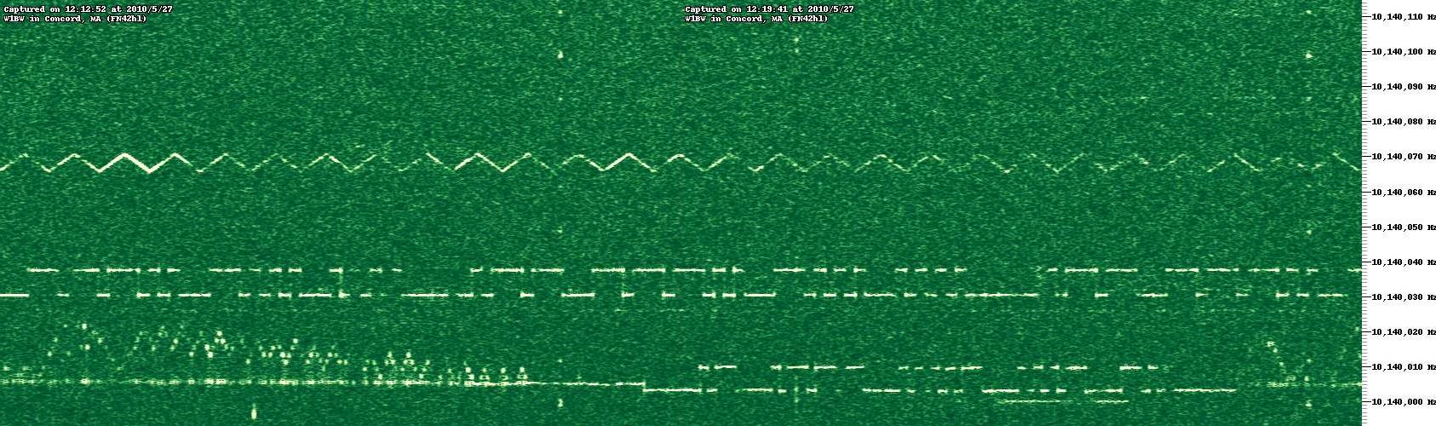
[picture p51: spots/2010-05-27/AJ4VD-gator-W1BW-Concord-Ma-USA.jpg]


**Hiatus (Aug, 2011):** I actively experimented with QRSS almost every day until August, 2011 when a large change in my personal life led me to put the hobby down. As part of a move I boxed-up all my electronics equipment, and I never got around to pulling it out. I broke-out some equipment in 2013 and again in 2015 with the goal of building an ovenized transmitter, but got so distracted with temperature regulation (both times) that I burned out before I ever made anything meaningful. I was inspired by Eldon Brown (WA0UWH)'s [SMT oscillators](http://wa0uwh.blogspot.com/search/label/Marker) and even printed a picture of one of them and put it on my wall so I wouldn't forget to build something similar one day. That picture sat there for a few years, but eventually got taken down when I moved.

**QRSS Plus (July, 2013):** Although I didn't keep-up experimenting with QRSS _hardware_ for several years, I quietly followed the QRSS mailing lists. I noticed that a huge amount of posts were people saying, "I just turned on my grabber", or "my grabber is going offline" and I thought it would be useful to make an automatically-updating active QRSS grabber list. I called the project [QRSS Plus](http://swharden.com/qrss/plus/) I first implemented it entirely in PHP in July 2013. I recoded the back-end in Python in 2016, and the front-end is still PHP. I'm proud that QRSS Plus has been continuously running since 2013!

**Returning to QRSS (July, 2019):** During my QRSS hiatus I continued to work on software and hardware projects. Although none of them were in the RF/QRSS world, getting back into this hobby was always been in the back of my mind. [Medical issues](http://www.swharden.com/med/) made me stop all projects for about 6 months, but during my recovery I found myself wanting to get back into QRSS more than ever. Once I felt well enough I strung-up an attic antenna and built a QRSS transmitter. I first first spotted my signal on July 13, 2019. AJ4VD is back on the air! We will see where it goes from here...

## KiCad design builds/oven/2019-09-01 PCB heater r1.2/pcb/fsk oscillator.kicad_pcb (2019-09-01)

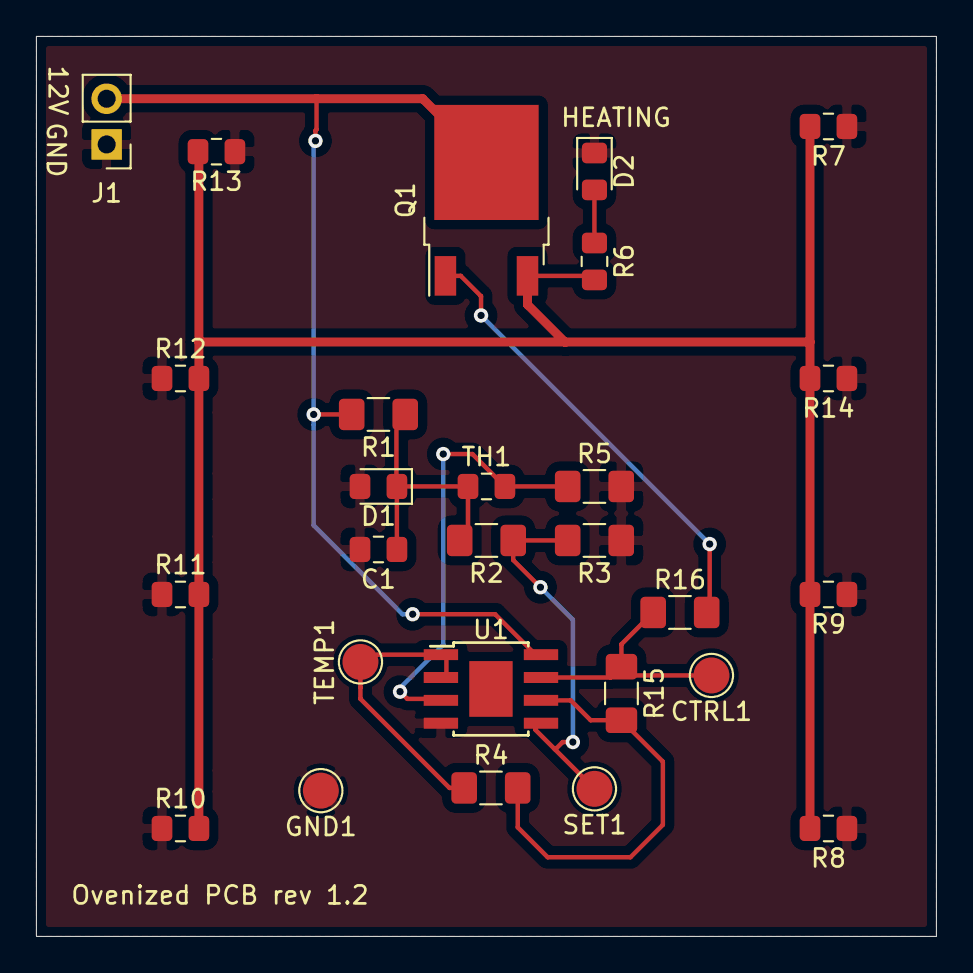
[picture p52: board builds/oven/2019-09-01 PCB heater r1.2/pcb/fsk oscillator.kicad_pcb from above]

Board: 2 copper layers, 50.0 x 50.0 mm, 27 parts (0 on the bottom side), 11 nets.

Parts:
C1: .1u; C_0805_2012Metric_Pad1.15x1.40mm_HandSolder
CTRL1: TestPoint; TestPoint_Pad_D2.0mm
D1: 10V; D_0805_2012Metric_Pad1.15x1.40mm_HandSolder
D2: HEATING; LED_0805_2012Metric_Pad1.15x1.40mm_HandSolder
GND1: TestPoint; TestPoint_Pad_D2.0mm
J1: Conn_01x02_Male; PinHeader_1x02_P2.54mm_Vertical
Q1: MJD122; TO-252-2
R1, R4, R16: 1k; R_1206_3216Metric_Pad1.42x1.75mm_HandSolder
R2, R3, R5, R15: 10k; R_1206_3216Metric_Pad1.42x1.75mm_HandSolder
R6: 10k; R_0805_2012Metric_Pad1.15x1.40mm_HandSolder
R7, R8, R9, R10, R11, R12, R13, R14: 330; R_0805_2012Metric_Pad1.15x1.40mm_HandSolder
SET1: TestPoint; TestPoint_Pad_D2.0mm
TEMP1: TestPoint; TestPoint_Pad_D2.0mm
TH1: NTC; R_0805_2012Metric_Pad1.15x1.40mm_HandSolder
U1: LM358_DFN; TI_SO-PowerPAD-8

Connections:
+12V: J1.2, Q1.2, R1.2, U1.8
GND: C1.2, D1.2, D2.1, GND1.1, J1.1, R3.1, R5.2, R7.1, R8.1, R9.1, R10.1, R11.1, R12.1, R13.1, R14.1, U1.4
unnamed: CTRL1.1, R15.1, R16.1, U1.7
unnamed: D2.2, R6.1
unnamed: Q1.1, R16.2
unnamed: Q1.3, R6.2, R7.2, R8.2, R9.2, R10.2, R11.2, R12.2, R13.2, R14.2
unnamed: R2.1, R3.2, SET1.1, U1.5
unnamed: R4.1, TEMP1.1, U1.1, U1.2
unnamed: R5.1, TH1.2, U1.3
unnamed: R4.2, R15.2, U1.6
REF: C1.1, D1.1, R1.1, R2.2, TH1.1

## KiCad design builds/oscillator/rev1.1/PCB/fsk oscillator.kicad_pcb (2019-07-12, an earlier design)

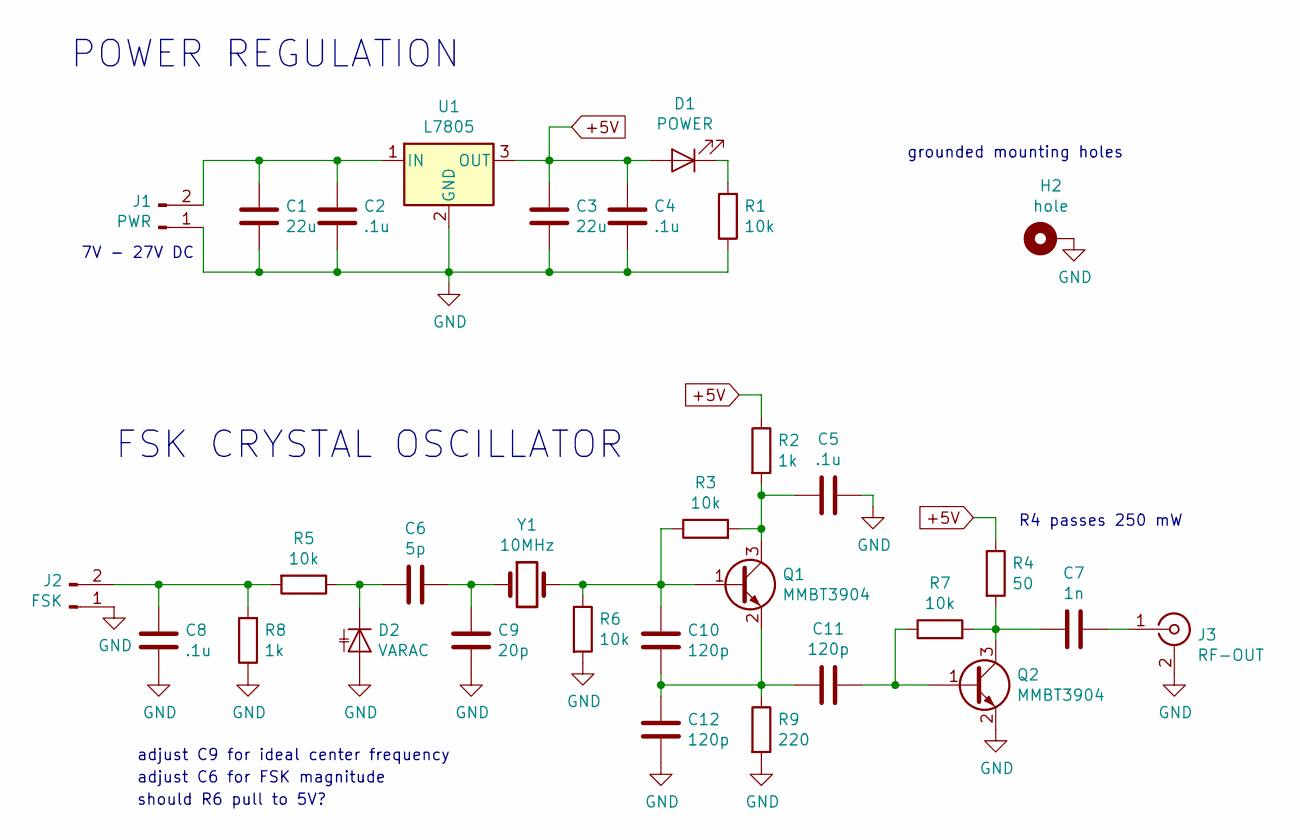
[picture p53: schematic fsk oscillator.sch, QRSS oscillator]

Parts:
C1, C3: 22u; C_0805_2012Metric_Pad1.15x1.40mm_HandSolder
C2, C4, C5, C8: .1u; C_0805_2012Metric_Pad1.15x1.40mm_HandSolder
C6: 5p; C_0805_2012Metric_Pad1.15x1.40mm_HandSolder
C7: 1n; C_0805_2012Metric_Pad1.15x1.40mm_HandSolder
C9: 20p; C_0805_2012Metric_Pad1.15x1.40mm_HandSolder
C10, C11, C12: 120p; C_0805_2012Metric_Pad1.15x1.40mm_HandSolder
D1: POWER; LED_0805_2012Metric_Pad1.15x1.40mm_HandSolder
D2: VARAC; LED_0805_2012Metric_Pad1.15x1.40mm_HandSolder
H2: hole; MountingHole_4.3mm_M4_ISO7380_Pad
J1: PWR; PinHeader_1x02_P2.54mm_Vertical
J2: FSK; PinHeader_1x02_P2.54mm_Vertical
J3: RF-OUT; SMA_Amphenol_132134-16_Vertical
Q1, Q2: MMBT3904; SOT-23
R1, R3, R5, R6, R7: 10k; R_0805_2012Metric_Pad1.15x1.40mm_HandSolder
R2, R8: 1k; R_0805_2012Metric_Pad1.15x1.40mm_HandSolder
R4: 50; R_1206_3216Metric_Pad1.42x1.75mm_HandSolder
R9: 220; R_0805_2012Metric_Pad1.15x1.40mm_HandSolder
U1: L7805; TO-252-3_TabPin2
Y1: 10MHz; Crystal_HC49-U_Horizontal_1EP_style2

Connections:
+5V: C3.1, C4.1, D1.2 (A), R2.1, R4.1, U1.3 (OUT)
GND: C1.2, C2.2, C3.2, C4.2, C5.1, C8.2, C9.2, C12.2, D2.2 (A), H2.1, J1.1, J2.1, J3.2 (Ext), Q2.2 (E), R1.1, R6.2, R8.1, R9.2, U1.2 (GND); also elsewhere on the board
unnamed 2: C1.1, C2.1, J1.2, U1.1 (IN); also elsewhere on the board
unnamed: C5.2, Q1.3 (C), R2.2, R3.2
unnamed: C6.1, D2.1 (K), R5.1
unnamed: C6.2, C9.1, Y1.1
unnamed 6: C7.1, J3.1 (In); also elsewhere on the board
unnamed: C7.2, Q2.3 (C), R4.2, R7.2
unnamed 8: C8.1, J2.2, R5.2, R8.2; also elsewhere on the board
unnamed: C10.1, Q1.1 (B), R3.1, R6.1, Y1.2
unnamed: C10.2, C11.2, C12.1, Q1.2 (E), R9.1
unnamed: C11.1, Q2.1 (B), R7.1
unnamed: D1.1 (K), R1.2

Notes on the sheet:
POWER REGULATION
7V - 27V DC
adjust C6 for FSK magnitude
adjust C9 for ideal center frequency
FSK CRYSTAL OSCILLATOR
should R6 pull to 5V?
R4 passes 250 mW
grounded mounting holes

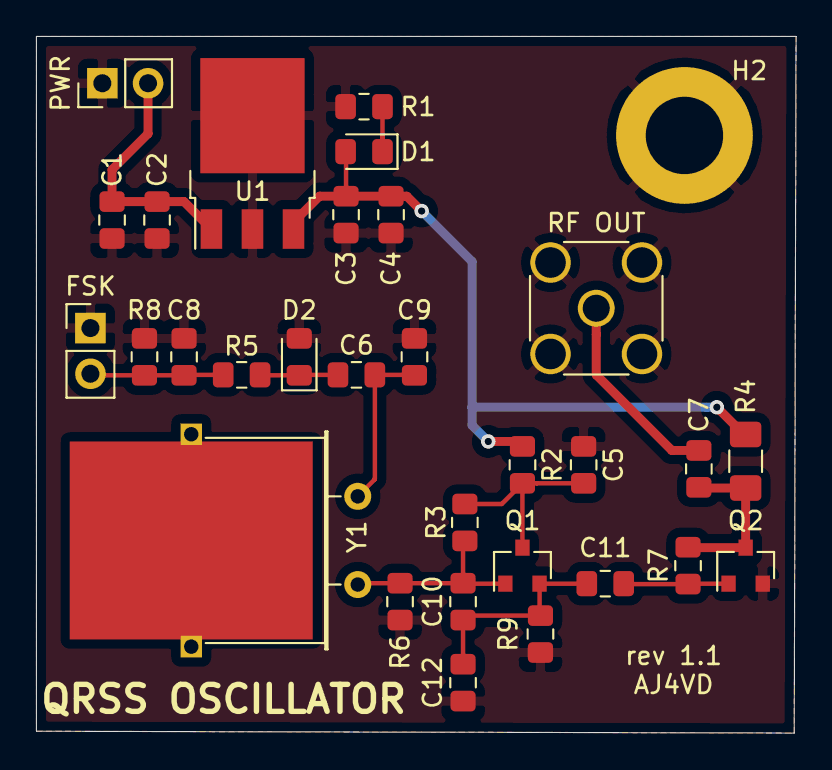
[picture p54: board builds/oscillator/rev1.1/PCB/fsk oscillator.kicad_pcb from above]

Board: 2 copper layers, 42.2 x 38.7 mm, 31 parts (0 on the bottom side), 13 nets.

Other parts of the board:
FSK: FSK; PinHeader_1x02_P2.54mm_Vertical
PWR: PWR; PinHeader_1x02_P2.54mm_Vertical
RF OUT: RF-OUT; SMA_Amphenol_132134-16_Vertical

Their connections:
GND: FSK.1, PWR.1, RF OUT.2; also elsewhere on the board
unnamed 2: PWR.2; also elsewhere on the board
unnamed 6: RF OUT.1; also elsewhere on the board
unnamed 8: FSK.2; also elsewhere on the board

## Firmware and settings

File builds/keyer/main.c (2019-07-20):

#define F_CPU 8000000UL
#define USART_BAUDRATE 9600
#define UBRR_VALUE (((F_CPU / (USART_BAUDRATE * 16UL))) - 1)

#include <avr/io.h>
#include <util/delay.h>
#include <avr/interrupt.h>

void setupPWM_8bit()
{
	DDRB |= (1 << PB2);					   // 8-bit PWM outputs on PB2
	TCCR0A = (1 << COM0A1) | (1 << WGM00); // phase correct PWM mode
	TCCR0B = (1 << CS00);				   // fastest (no prescaler)
	OCR0A = 128;						   // set PWM pulse width (duty)
}

void setupUSART()
{

	UBRRL = UBRR_VALUE;					  // set baud rate
	UCSRB |= (1 << RXCIE);				  // RX Complete Interrupt Enable
	UCSRB |= (1 << RXEN);				  // RX Enable
	UCSRC |= (1 << UCSZ1) | (1 << UCSZ0); // 8-bit data
	sei();								  // enable global interrupts
}

volatile char receivedBytes[20];
volatile char receivedByteIndex;
volatile char lastSeenMinuteDigit = 'x';

ISR(USART_RX_vect) // incoming serial byte
{
	char thisChar = UDR;

	if (thisChar == '$')
		receivedByteIndex = 0;

	if (receivedByteIndex < sizeof(receivedBytes))
		receivedBytes[receivedByteIndex++] = thisChar;
	else
		processFullBuffer();
}

void processFullBuffer()
{
	// look for a message like:
	//   $GPRMC,184130.00,...
	// which means time:
	//   18:41:30.00
	// and note the digit in the tens place

	uint8_t indexMinutesTens = 9;
	uint8_t indexMinutesOnes = 10;
	uint8_t indexSecondsTens = 11;
	uint8_t indexSecondsOnes = 12;

	// see if the line starts with "$GPRMC"
	if ((receivedBytes[0] == '$') && (receivedBytes[5] == 'C'))
		lastSeenMinuteDigit = receivedBytes[indexMinutesOnes];

	receivedByteIndex = 0; // reset the buffer
}

void waitForNextFiveMinuteMark()
{
	for (;;)
	{
		if (lastSeenMinuteDigit == '0')
			return;
		if (lastSeenMinuteDigit == '5')
			return;
	}
}

void waitForNextTenMinuteMark()
{
	for (;;)
	{
		if (lastSeenMinuteDigit == '0')
			return;
	}
}

void waitSec(int seconds)
{
	while (seconds--)
		_delay_ms(1000);
}

void waitMilliSec(int milliseconds)
{
	while (milliseconds--)
		_delay_ms(1);
}

int pwmHigh = 200;
int pwmLow = 100;
int rampUpSpeed = 50;
int rampDownSpeed = 2;

void ramp(int target, int speed)
{
	if (OCR0A < target)
	{
		while (OCR0A < target)
		{
			OCR0A += 1;
			waitMilliSec(speed);
		}
	}
	else if (OCR0A > target)
	{
		while (OCR0A > target)
		{
			OCR0A -= 1;
			waitMilliSec(speed);
		}
	}
}

int dashSeconds = 9;

void sendDot()
{
	ramp(pwmHigh, rampUpSpeed);
	waitSec(dashSeconds);
	txOFF();
	ramp(pwmLow, 0);
	waitSec(dashSeconds);
	txON();
}

void sendDash()
{
	ramp(pwmHigh, rampUpSpeed);
	waitSec(dashSeconds * 2);
	txOFF();
	ramp(pwmLow, 0);
	waitSec(dashSeconds);
	txON();
}

void sendPreLetter()
{
	OCR0A = pwmLow;
	waitSec(dashSeconds);
}

void sendCallsign()
{
	// A
	sendPreLetter();
	sendDot();
	sendDash();

	// J
	sendPreLetter();
	sendDot();
	sendDash();
	sendDash();
	sendDash();

	// 4
	sendPreLetter();
	sendDot();
	sendDot();
	sendDot();
	sendDot();
	sendDash();

	// V
	sendPreLetter();
	sendDot();
	sendDot();
	sendDot();
	sendDash();

	// D
	sendPreLetter();
	sendDash();
	sendDot();
	sendDot();
}

void testOOK()
{
	int repeats = 5;
	while (repeats--)
	{
		txON();
		waitSec(1);
		txOFF();
		waitSec(1);
	}
}

void testFSK()
{
	int repeats = 5;
	while (repeats--)
	{
		OCR0A = pwmHigh;
		waitSec(1);
		OCR0A = pwmLow;
		waitSec(1);
	}
}

void txON()
{
	PORTD &= ~(1 << PD5);
}

void txOFF()
{
	PORTD |= (1 << PD5);
}

void testDitsForever()
{
	for (;;)
	{

		txON();
		sendPreLetter();
		sendDot();
		txOFF();

		waitSec(30);
	}
}

void sendCallsignForever()
{
	for (;;)
	{
		waitForNextTenMinuteMark();
		txON();
		sendCallsign();
		txOFF();
	}
}

int main(void)
{
	setupPWM_8bit();
	setupUSART();

	//testFSK();
	//testOOK();
	
	txOFF();

	//testDitsForever();
	sendCallsignForever();
}

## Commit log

2019-07-12 initial upload
    [fsk oscillator.kicad_pcb, fsk oscillator.sch]
2019-07-14 varactor notes
    [varactor.kicad_pcb, varactor.sch]
2019-07-14 lazy oven
    [oven.kicad_pcb, oven.sch]
2019-07-15 crystal oven
    [oven.kicad_pcb, oven.sch]
2019-07-15 chassis heater notes
    [oven-lazy.sch]
2019-07-15 fix schematic
    [oven-lazy.sch, oven.sch]
2019-07-21 update keyer notes
    [fsk-circuit.sch]
2019-07-28 ovenize pcb
    [fsk oscillator.kicad_pcb, fsk oscillator.sch, varactor.kicad_pcb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]
2019-07-28 update resistor info
2019-08-01 add amplifier schematic
    [amplifier.kicad_pcb, amplifier.sch]
2019-08-29 start pcb heater
    [pcb-heater.kicad_pcb, pcb-heater.sch]
2019-09-01 pcb oven r1.2
    [fsk oscillator.kicad_pcb, fsk oscillator.sch, pcb-heater.kicad_pcb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]
